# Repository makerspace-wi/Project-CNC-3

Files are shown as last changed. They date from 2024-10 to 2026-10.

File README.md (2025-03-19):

# Project-CNC-3

<br><br>
[Zur Dokumentation](https://makerspace-wi.github.io/Project-CNC-3/)<br><br>
Die CNC-3 ist ein Privatprojekt von Klaus F., dass vor einigen Jahren aus seinem Keller in den Makerspace umgezogen wurde.  
Sein Ziel war es, aus einem Bausatz eine robuste & präzise CNC-Fräse mit großer Arbeitsfläche zu bauen, die in erster Linie für Metallwerkstoffe ausgelegt ist.  
Seine Entscheidung fiel damals auf eine (China) HF-Spindel mit 24000U/min und 'Closed Loop' Steppermotor Antriebe für die 3 Achsen.  
Leider ist Klaus schon längere Zeit erkrankt, lebt momentan in einem Pflegeheim und das Projekt stand damit lange Zeit unbeachtet in unserer Metallwerkstatt.  
Gegen Ende 2024 rekrutierte das Makerspace Technikteam eine kleine Gruppe zur Fertigstellung der Fräse und es fanden sich auch Unterstützer, die das Projekt mit größeren Geldsummen mitfinanzierten. Weitere Mittel kamen aus Vereinsguthaben - wir danken an dieser Stelle auch noch mal unserem Finanzvorstand.
Diese Zusammenfassung wurde im März 2025 geschrieben, die CNC-3 ist tatsächlich kurz vor der Fertigstellung und wir sind alle sehr gespannt.
Damit ist dann auch die Zeit gekommen, wo wir kräftig dokumentieren müssen - den Einstieg findet ihr [hier](https://makerspace-wi.github.io/Project-CNC-3/)

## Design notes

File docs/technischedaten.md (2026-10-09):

## Technische Daten:
X-Achse mit 1x NEMA23 - LC57H3100 3,0Nm  4,0A & 2x mech. Endstopp (min & max)  
Y-Achse mit 1x NEMA23 - LC57H3100 3,0Nm  4,0A & 2x mech. Endstopp (min & max)  
Z-Achse mit 1x NEMA23 - LC57H380  2,0Nm  3,5A & 1x mech. Endstopp (min & max)  
    
Fräs-Spindel:Teknomotor 1,1KW ER20 230V/380V mit E-Lüfter
### Arbeitsfläche
T-Nutenplatte PT-50 von der Firma isel<br>
8mm Nuten für M6 Nutensteine  
X-Achse 700mm  
Y-Achse 1100mm  

### Fräsfläche:
X-Achse 620mm  
Y-Achse 995mm  
Z-Hub 115mm  
  
Steuerprogramm: <a href="https://www.estlcam.de/" target="_blank">Estlcam</a> von Christian Knüll (Homepage enthält auch weitere Hilfen)  
Controller: <a href="https://www.estlcam.de/tx.php/" target="_blank">Klemmenadapter XL</a> (auch von Christian Knüll)  
Minimalmengenschmierung (MMS) von <a href="https://www.end-cnc-shop.de/" target="_blank">END-CNC</a>

[Zurück zum Start](https://makerspace-wi.github.io/Project-CNC-3/)

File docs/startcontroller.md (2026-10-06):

# CNC-Controller starten

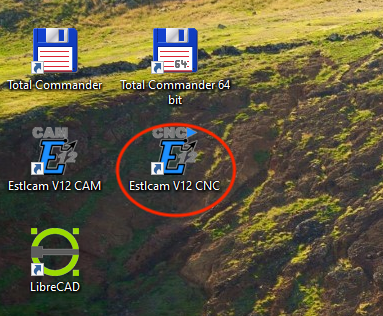
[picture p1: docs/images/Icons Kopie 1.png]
ESTLCAM Icons
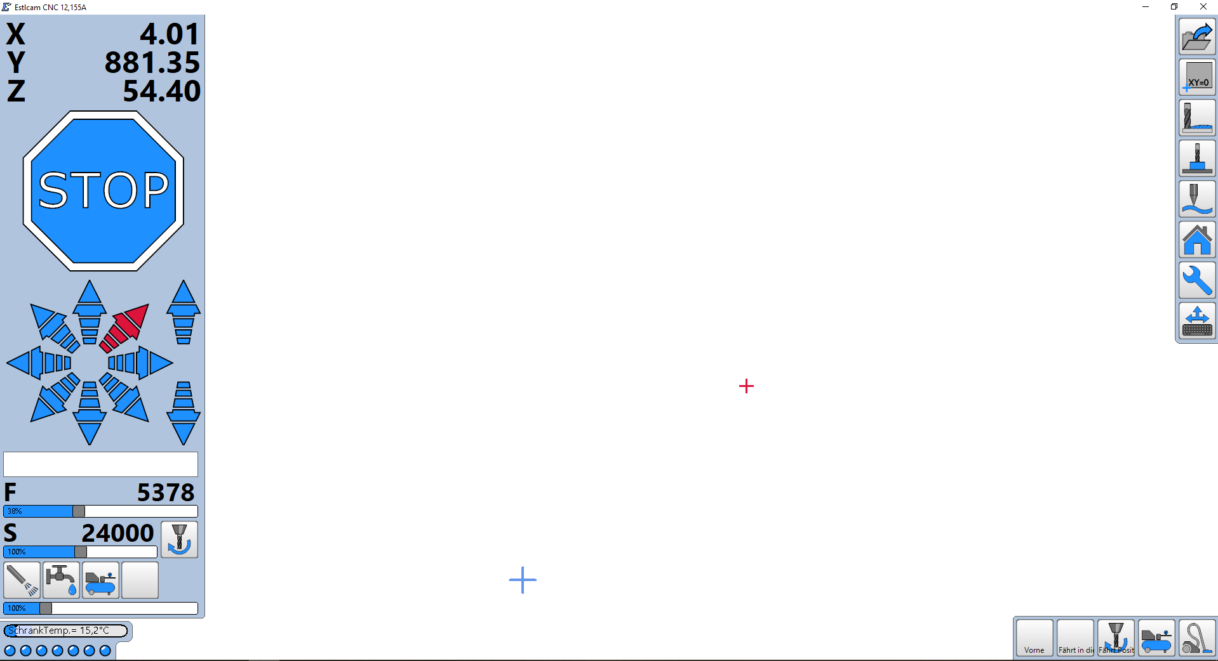
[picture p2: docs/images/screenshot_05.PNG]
CNC Controller Bildschirm
 

Der CNC-Controller wird durch Doppelklick von **Estlcam V12 CNC** auf der Oberfläche gestartet, damit werden alle Achsentreiber aktiviert, d.h. der Fräsmotor kann ab jetzt mittels Fernsteuerung, Maus oder Direkteingabe an eine Position fahren.

**Hinweis:** Jedes Feld, jede Funktion wird auf dem Bildschirm ausführlich erklärt, wenn man den Mauszeiger darüber positioniert.

## HILFE! - Ich habe eine Achse in den Endstopp gefahren 😱

Wenn dies passiert ist - bitte einfach die Ruhe bewahren! Die Software hat sofort alle Bewegungen gesperrt und am unteren Rand des Bildschirms wird auch darauf hingewiesen (in roter Schrift & blinkend). In diesem Fall die 'F11' Taste gedrückt halten und die betroffene Achse **manuell aus dem Endstopp** fahren (bei gedrückter F11-Taste darauf achten, dass in die richtige Richtung gefahren wird, also weg vom Endstopp).
  
  Wenn man trotz aller Vorsicht den Fräser auf das Werkstück gerammt hat (z.B. beim Z-Antaten), hat man einen Schleppfehler auf Z und muss unbedingt Homing/Referenzfahrt durchführen.

[Funktionen Fernsteuerung](fernsteuerung.md)

[Steuerung per Maus & Tastatur (YouTube Video)](https://www.youtube.com/watch?v=sXvNqufWKvA)

[Macros](macros.md)

[Minimalmmengenschmierung (MMS)](mms.md)

[Zurück zum Start](https://makerspace-wi.github.io/Project-CNC-3/#hilfestellungen-zum-fr%C3%A4sjob)

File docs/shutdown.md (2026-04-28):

# CNC-Fräse sicher herunterfahren

Der Shutdown-Prozess muss immer in der gleichen Reihenfolge erfolgen, damit keine Achse unerwartet fährt und die Maschine sauber für den nächsten Nutzer übergeben wird.

## Reihenfolge: Shutdown nach dem Fräsen

1. **Fräsjob beenden**  
	Warten, bis alle Achsen stehen und die Spindel komplett aus ist.
1. **MMS/Kühlung ausschalten**  
 Links unten - Falls genutzt: [MMS stoppen](mms.md)
1. **Makro [*Mitte*](macros.md) aufrufen (2. Button von links)**  
    Die Z-Achse wird in ihre maximale Höhe und Fräser weg vom Werkstück bewegt, damit Werkstück und Spannmittel gut zugänglich sind.
1. **Spannmittel lösen und Werkstück entnehmen**  
	Vorsichtig ausspannen, scharfe Kanten beachten.
1. **Maschine reinigen**  
	Späne an Tisch, Führungen und im Arbeitsraum entfernen; Werkzeugaufnahme sauber halten.
1. **Sichtprüfung auf Beschädigungen**  
	Fräser, Spannzange, Kabel und Not-Aus Bereich kurz kontrollieren.
1. **In ESTLCAM den Home Button betätigen**  
	Es wird dann die Referenzfahrt ausgeführt und die Fräse wird in die hintere, linke Ecke positioniert.	
1. **ESTLCAM sauber schliessen und PC runter fahren**  
	Dateien sichern, Projekte speichern, Programme geordnet beenden.
1. **Ausloggen am Lesegerät**  
    Die grüne Taste muss unbedingt vor dem Ausschalten des Hauptschalters gedrückt werden.   
1. **Hauptschalter ausschalten**  
	Erst ganz am Ende die Gesamtversorgung trennen.

## Sonderfall: Werkzeugwechsel während eines Jobs

* Maschine anhalten und Spindelstillstand abwarten.
* Fräser wechseln wie in der Fräser-Anleitung beschrieben.
* **Z-Nullpunkt zwingend neu setzen**, danach erst Job fortsetzen.

## Übergabe-Check

* Arbeitsfläche sauber
* Werkzeuge und Schlüssel aufgeräumt
* Keine Warnmeldung aktiv
* Maschine in sicherem Endzustand

[Reinigung](reinigung.md)

[Zurück zum Start](https://makerspace-wi.github.io/Project-CNC-3/)

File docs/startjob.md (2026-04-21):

# Fräsjob starten  

1. **Projekt/Fräsfile muss in ESTLCAM geladen sein.**  
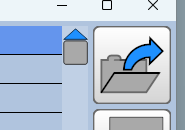
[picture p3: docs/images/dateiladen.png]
  
<br>
1. **Die angezeigte Spindeldrehzahl und der zu nutzende Fräser wird angezeigt und sollte unbedingt nochmals geprüft werden.**  
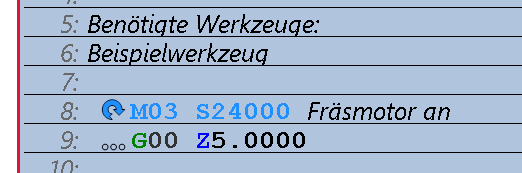
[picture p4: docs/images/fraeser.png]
  
<br>
1. **Der Fräsjob wird nach dem Betätigen des Dreiecks gestartet.**  
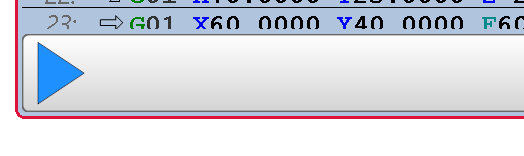
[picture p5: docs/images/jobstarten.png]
  
<br>
1. **Das Programm kann jederzeit angehalten werden und zwar durch**  
    - nochmaliges Drücken der Starttaste  
    - Bestätigen des großen STOP-Buttons (färbt sich rot mit Maus)  
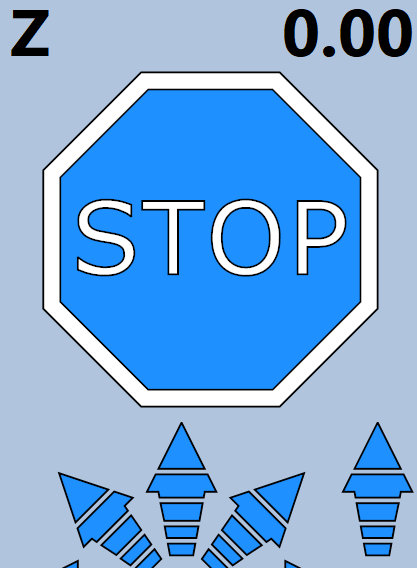
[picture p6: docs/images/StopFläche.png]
      
    - Drücken der Escape(Esc) Taste auf der Tastatur  
<br>

[Zurück zum Start](https://makerspace-wi.github.io/Project-CNC-3/)

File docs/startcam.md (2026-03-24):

# CAM-Controller starten und Projektfile anlegen

**Jeder kann sich eine Demo-Version der aktuellen [ESTLCAM Software](https://www.estlcam.de/) zu Hause auf seinem Windows-Rechner installieren, um ESTLCAM zu studieren und/oder die eigene Werkzeugliste anzulegen.** 

**Apple Nutzer können gerne das installierte ESTLCAM auf dem Rechner im Elektronikraum nutzen.**

Hinweis: Jedes Feld, jede Funktion wird auf dem Bildschirm ausführlich erklärt, wenn man den Mauszeiger darüber positioniert.  

Nach Start des CAM-Modules wird folgender Bildschirm angezeigt, immer mit der Standard Werkzeugliste.

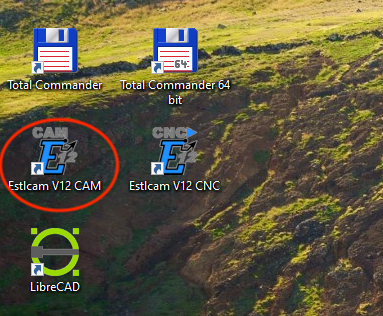
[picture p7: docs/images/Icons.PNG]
ESTLCAM Icons
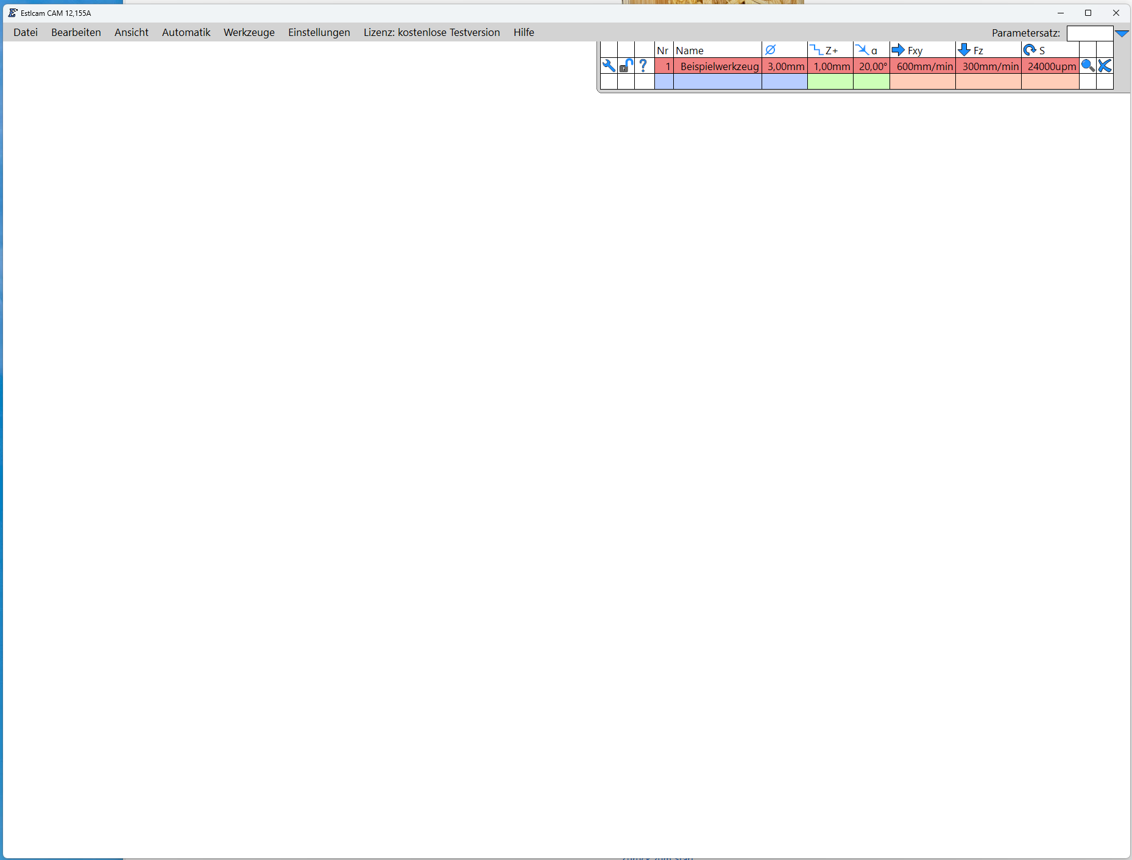
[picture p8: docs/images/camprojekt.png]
CAM Projekt Ansicht
 

## Voraussetzungen und Annahmen

- der Nutzer hat sich bereits ***intensiv*** mit allen von ESTLCAM zur Verfügung gestellten Funktionen auseinander gesetzt (wird während der Einweisung geprüft!)
- der Nutzer ist im Besitz eines dedizierten USB-Sticks
- der Nutzer hat sich ein eigenes Set an benötigten Fräsern angeschafft (Einweisung ggf. mit vorhandenen Fräsern)
- der Nutzer hat seine 2D- (DXF oder SVG) oder 3D-Zeichnung (STL) erstellt und auf dem USB-Stick gespeichert

Jeder Neuling muss zuerst alle Fräserparameter des eigenen Fräsersets in die Werkzeugliste eintragen.

[Werkzeugliste anlegen](werkzeugliste.md)

Ist dies geschehen, unbedingt die Werkzeugliste auf dem eignen USB-Stick mit eindeutigem Namen abspeichern, damit sie bei weiteren Nutzungen wieder geladen werden kann.

Also **immer** zu Beginn eines neuen Projekts **zuerst** die zu bearbeitende Zeichnung und erst dann die eigene Werkzeugliste laden, oder die Projektliste eines bereits begonnenem Projekts öffnen (dabei wird dann die korrekte Werkzeugliste angezeigt).

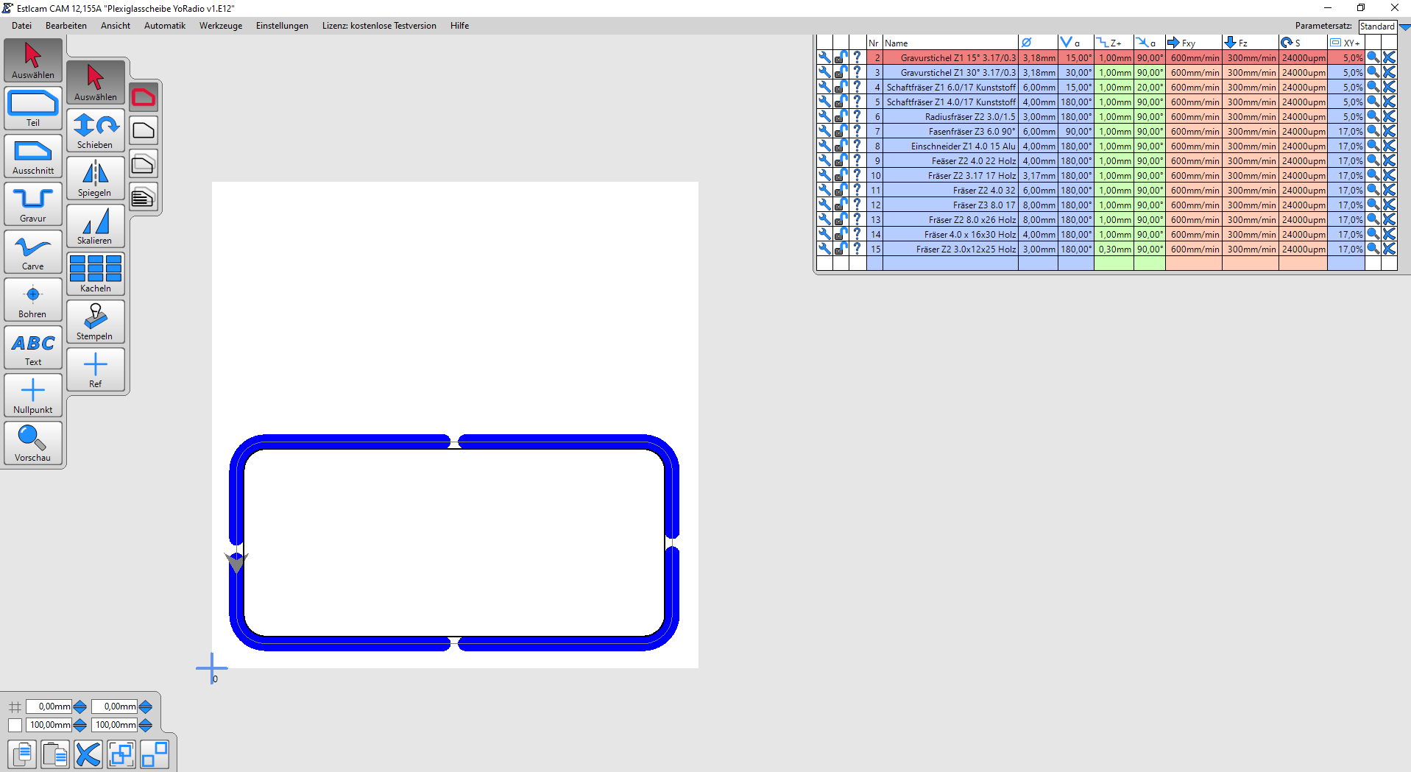
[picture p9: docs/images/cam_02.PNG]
CAM Werkzeugliste laden


An dieser Stelle wird definiert, was, wie und mit welchem Fräser gearbeitet werden soll (Aussenkanten, Ausschnitte, Taschen, Gravuren, Bohren, Texte setzen, Projektnullpunkt usw.). Dies wird bei der Einweisung an einem einfachen Projekt praktiziert und erfordert jede Menge Eigeninitiative alle ESTLCAM Funktionen zu verstehen und anzuwenden.

Am Ende dann im Menü Datei '***Projekt speichern***' wählen, dabei wird dann auch die genutzte Werkzeugliste für dieses Projekt gespeichert.

Die Projektdatei ist die wichtigste Datei, da sie alle Details enthält und auch spätere Änderungen zulässt.

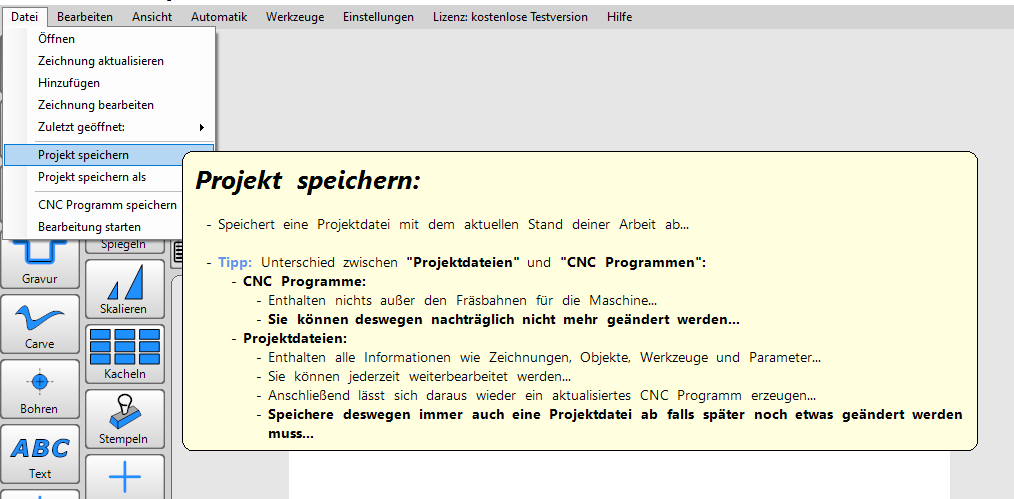
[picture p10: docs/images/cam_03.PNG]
CAM Projekt speichern


An dieser Stelle dann unbedingt die Vorschau starten und

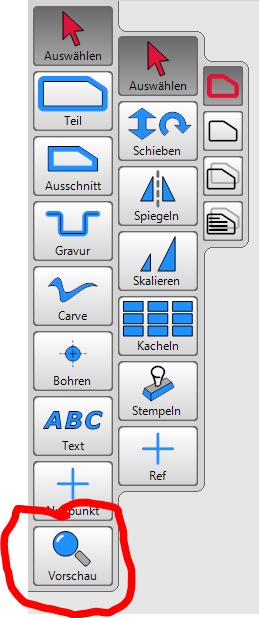
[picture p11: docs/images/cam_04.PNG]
CAM Vorschau Button


Die Anzeige für die Frässimulation ist zuerst die **Draufsicht**:

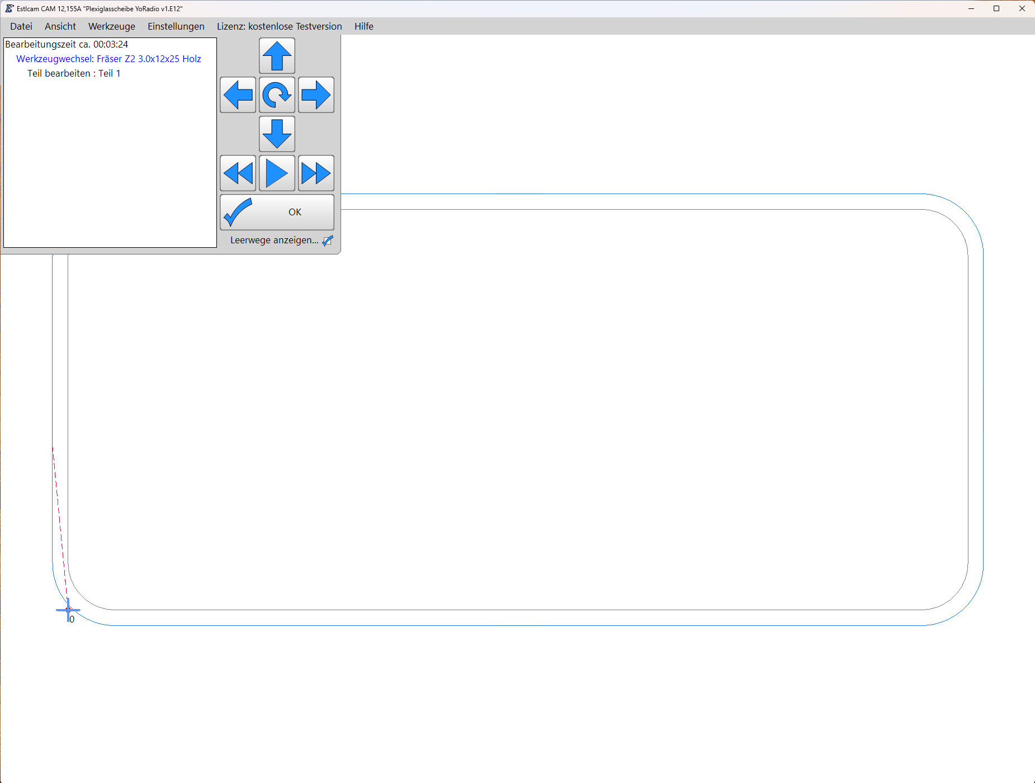
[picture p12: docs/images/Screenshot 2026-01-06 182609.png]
Frässimulation Draufsicht


ein Doppelklick auf die Bildschirmfläche führt zur zur **Raumansicht**:

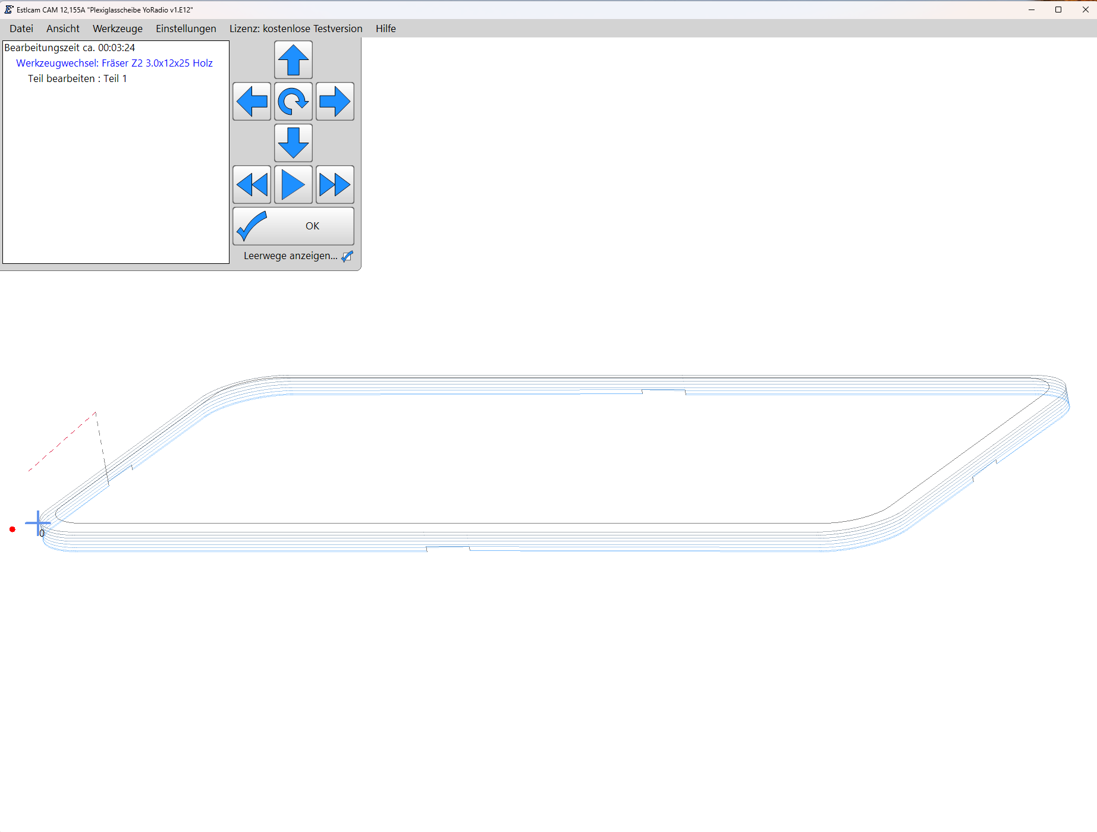
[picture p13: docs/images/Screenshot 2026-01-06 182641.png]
Frässimulation Raumsicht


ein weiterer Doppelklick bringt dich zur **Seitenansicht**:

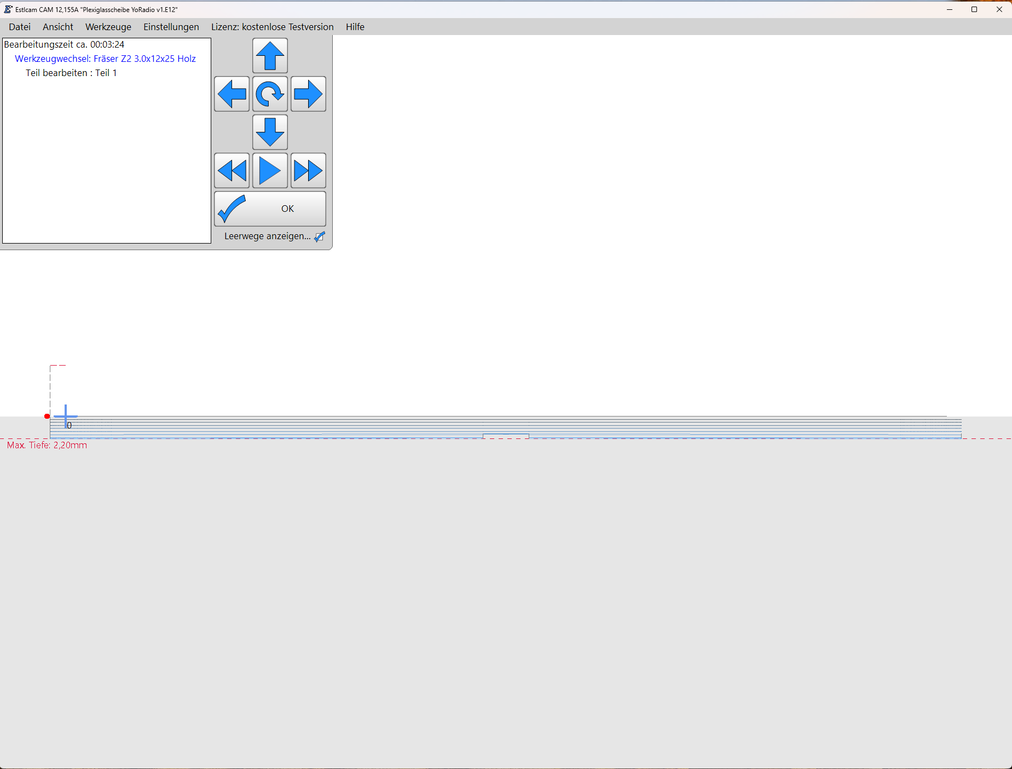
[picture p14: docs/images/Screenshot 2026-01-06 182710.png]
Frässimulation Seitenansicht


Diese Ansicht bitte genau bewerten, da sie die tatsächliche Frästiefe zeigt. <span style="color: red;">**Diese darf auf keinen Fall die Höhe von Werkstück plus Opferplatte überschreiten**</span> da die Nullung auf dem Werstück erfolgt!

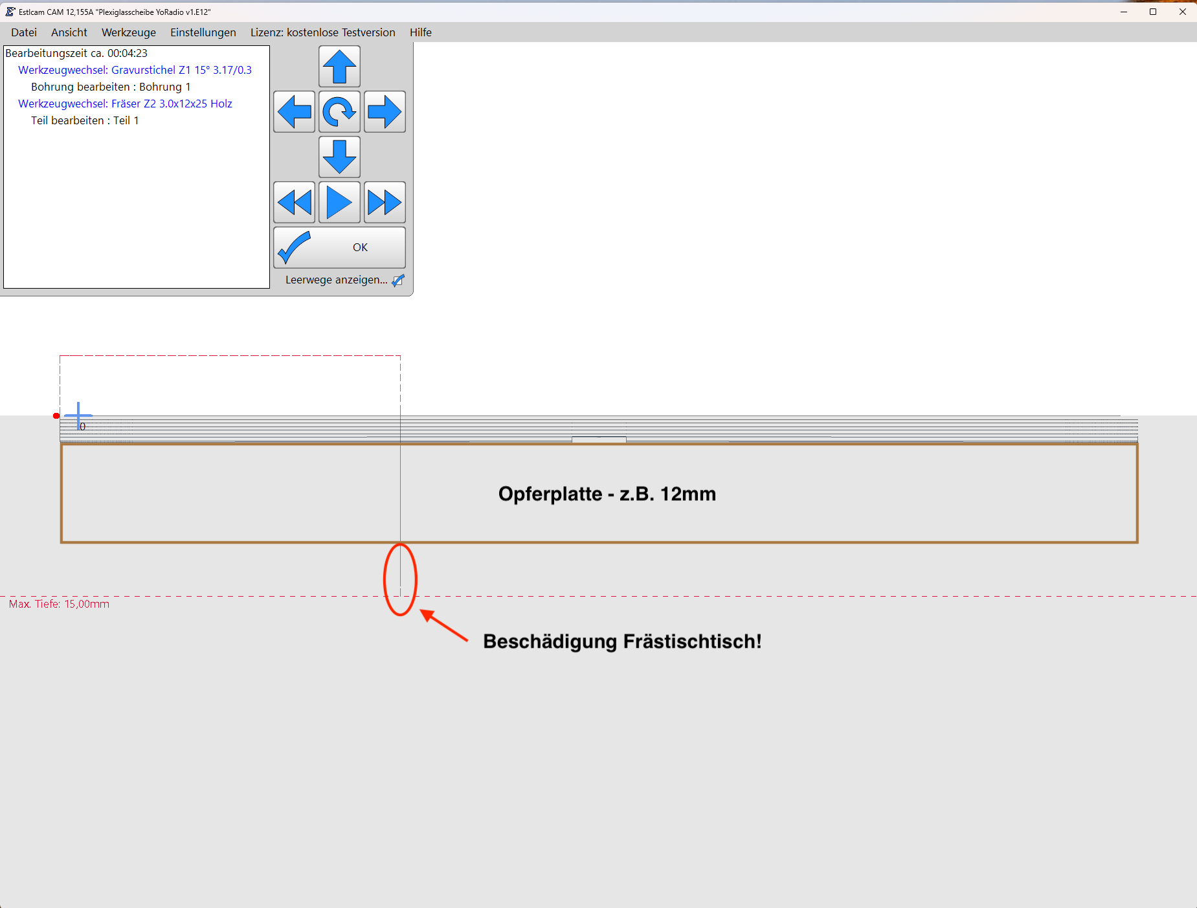
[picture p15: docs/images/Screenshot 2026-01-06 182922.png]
Frässimulation Details


Die Lage/Größe der Modellierung kann mit den Tasten oder der Maus angepasst werden. Mit der Starttaste wird die Simultion gestartet und erlaubt einen Einblick in die Fahrwege des Fräsers - der besondere Augenmerk muss dabei auf der Eintauchtiefe des Fräsers liegen. Die Simulationsgeschwindigkeit kann über die Doppeldreick-Tasten angepasst werden.

Ziel sollte es sein, das komplette Projekt mit einem Fräser abzuarbeiten, da die CNC's keinen Werkzeugwechsler haben.
Bei Projekten mit unterschiedlichen Fräsern wird zum Werkzeugwechsel die Maschine angehalten und muss nach Fräserwechsel und Z-Achsennullung wieder gestartet werden.

An dieser Stelle ist es sinnvoll, auch das **CNC Programm** zu speichern.

[Zurück](https://makerspace-wi.github.io/Project-CNC-3/#hilfestellungen-zum-fr%C3%A4sjob)  ---  [Weiter](startcontroller.md)

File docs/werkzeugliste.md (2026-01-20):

# Werkzeugliste

Die gezeigte Werkzeuglist ist lediglich ein Beispiel - die eigene Werkzeugliste sieht mit Sicherheit anders aus.

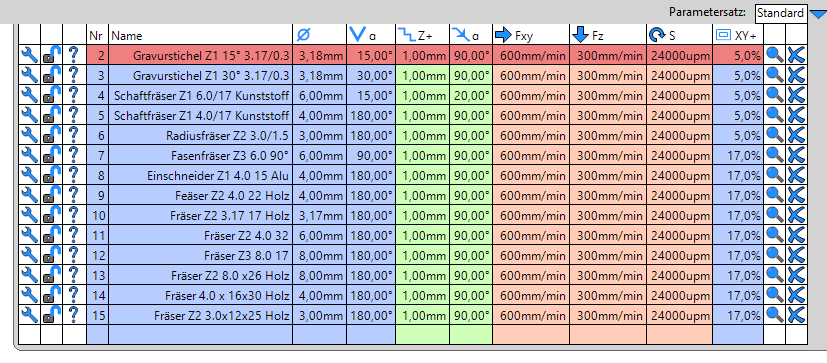
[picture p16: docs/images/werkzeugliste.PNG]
   

 Am besten gleich angewöhnen, beim Namen des Fräsers auch die wichtigsten Parameter mit anzugeben, z.B. Schaftfräser Z1 6.0/17 Kunststoff (Einzahn, Durchmesser 6mm, Frästiefe 17mm, Geeignet für Kunststoff)

Die folgenden Links unterstützen Euch beim anlegen der Werkzeugliste:  

- <a href="https://www.youtube.com/watch?v=hAuFUJFVQ4M" target="_blank">Die Listenansicht</a>
- <a href="https://www.youtube.com/watch?v=ulKHbmKEAJ8" target="_blank">Die Werkzeug Detailansicht</a>
- <a href="https://www.youtube.com/watch?v=FUI7nvCAFAw" target="_blank">Parametersätze</a>

Die Werkzeugliste kann Bilder der Fräser abspeichern und später anzeigen. Die jeweiligen Bild-Dateien können bei Sorotec oder HC-Maschinentechnik kopiert werden.  

Interessant ist es auch, sich mit dem Export als .csv Datei zu beschäftigen. Diese kann dann bequem in einem Tabellenprogramm bearbeitet werden.
 
[Zurück](startcam.md)

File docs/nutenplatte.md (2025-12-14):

# Nutenplatte

Sollte durch Fehleinstellung oder Unachtsamkeit in die Aluminium-Nutenplatte gefräst oder gebohrt werden, wird dies mit einem Betrag von € 50,-- geahndet.

Dieser Betrag wird in der Maschinenkasse hinterlegt und zu gegebener Zeit dazu verwendet, Ersatz zu beschaffen.<br>
Nach einer Beschädigung muss der Verursacher dies **zeitnah melden** und die € 50,-- zahlen.  

Wird eine Beschädigung ohne Meldung festgestellt, wird  <u>der letzte Nutzer</u> verpflichtet, den Betrag zu zahlen.
Daher ist es ratsam, unbedingt **vor** jedem Projekt zu prüfen, ob neue, nicht gemeldete Beschädigungen vorliegen.  

Beschädigungen werden im Maschinenlogbuch vermerkt.

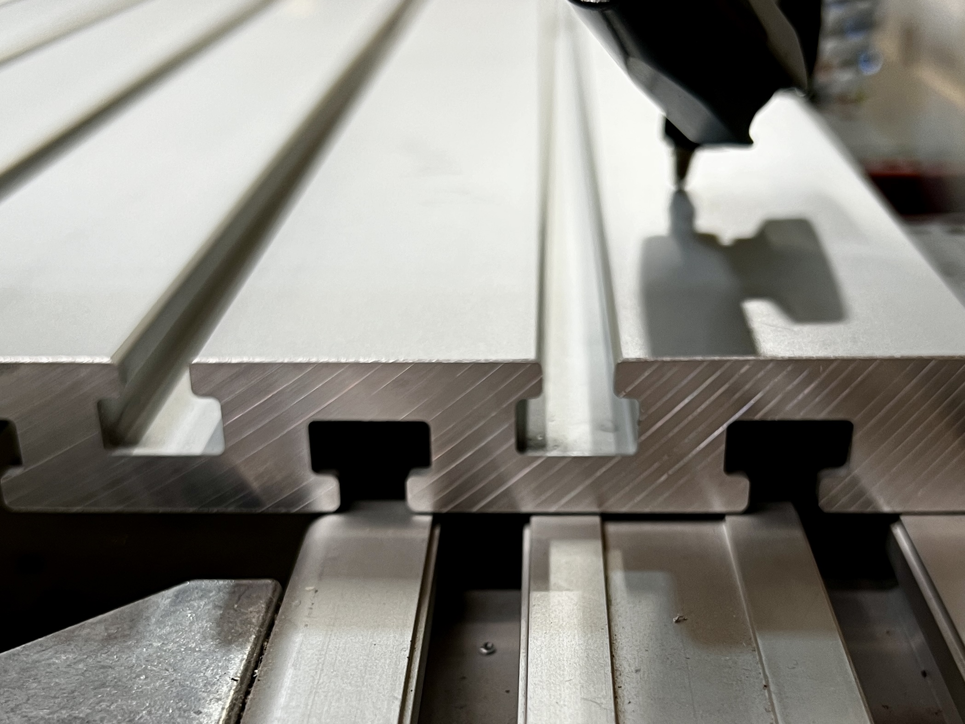
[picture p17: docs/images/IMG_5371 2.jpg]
  

[Zurück zum Start](https://makerspace-wi.github.io/Project-CNC-3/#vorbereitung)

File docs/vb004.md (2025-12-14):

# Toolslocker Zubehörbox  

Die Box im TOLO-2 beinhaltet alle notwendigen Zubehörteile wie Spannmutter, Spannzangen, Spannschlüssel, Hakenschlüssel, Konuswischer, Reinigungspinsel, T-Nutenmuttern usw. 

- <a href="https://www.upload.sorotec.de/doku/manuals/Merkblatt_Spannzangenwechsel.pdf" target="_blank">Merkblatt_Spannzangenwechsel</a>

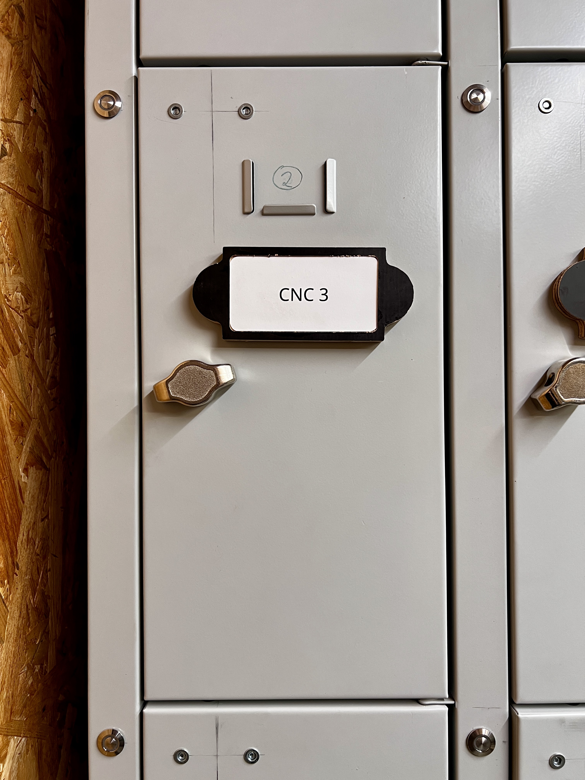
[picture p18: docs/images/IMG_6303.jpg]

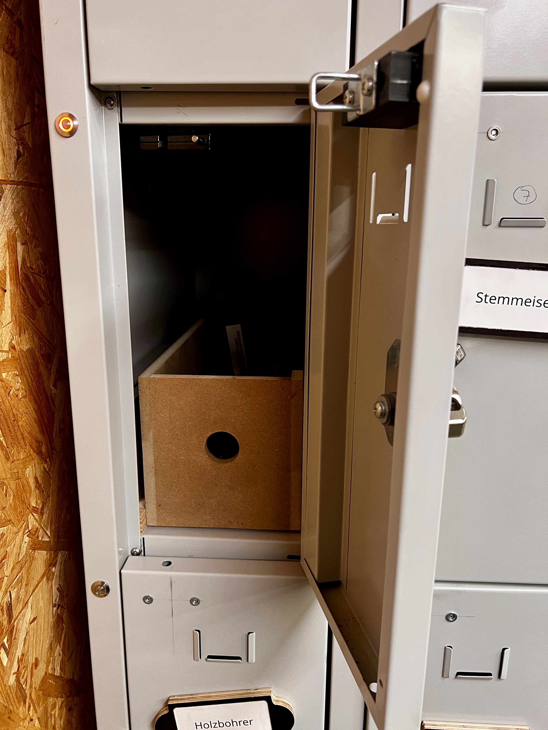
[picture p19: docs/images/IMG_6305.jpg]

  

### Spannzangenset ER 20 12teilig<br>Grössen: 2 ... 13 mm in 1 mm-Schritten plus Spannzange ER20 3,175 mm 

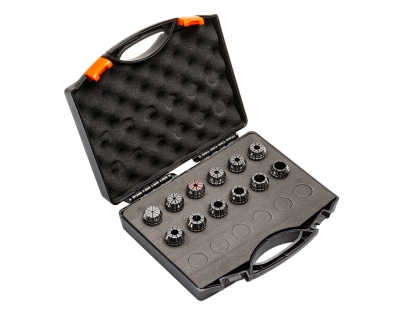
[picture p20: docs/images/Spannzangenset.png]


[Zurück zum Start](https://makerspace-wi.github.io/Project-CNC-3/#vorbereitung)

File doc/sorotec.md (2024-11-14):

# Dokumentation von SOROTEC
<strong>Handrad f&uuml;r Estlcam (EHR.ESTL.HR.01):</strong><ul>
<li><a href="https://www.upload.sorotec.de/doku/manuals/Handwheel Estlcam_data sheet_DE.pdf">Handwheel Estlcam_data sheet_DE.pdf</a>
<li><a href="https://www.upload.sorotec.de/doku/manuals/Handwheel Estlcam_data sheet_EN.pdf">Handwheel Estlcam_data sheet_EN.pdf</a></li></ul>

<strong>PUR-Motorenanschlussleitung 4 x 0,75 mm&sup2; + 2 x (2 x 0,34 mm&sup2;) (ELD.KBSG004.00.75.02.02.00.34):</strong>
<ul>
<li><a href="https://www.upload.sorotec.de/doku/manuals/SL_841_C_de.pdf">SL_841_C_de.pdf</a></li>
<li><a href="https://www.upload.sorotec.de/doku/manuals/SL_841_C_en.pdf">SL_841_C_en.pdf</a></li>
</ul>

<strong>FINDER-Koppelrelais 24 VDC 2 Wechsler 8 A (ELD.SRFIN49.52.9):</strong>
<ul>
<li><a href="https://www.upload.sorotec.de/doku/manuals/S4CDE.pdf">S4CDE.pdf</a></li>
</ul>

<strong>Schaltnetzteil 24V, 1 A, 20 W (ESN.02024):</strong>
<ul>
<li><a href="https://www.upload.sorotec.de/doku/manuals/SNTMWMDR20.pdf">SNTMWMDR20.pdf</a></li>
</ul>
<strong>Frequenzumrichter Omron M1 | 1,5 kW | 200 VAC | 1-phasig | max. 590 Hz (ZFU.1P1500.V.OM.M1):</strong>
<ul>
<li><a href="https://www.uplo=ad.sorotec.de/doku/manuals/Omron_3G3M1-AB015_Datenblatt.pdf">Omron_3G3M1-AB015_Datenblatt.pdf</a></li>
<li><a href="https://www.upload.sorotec.de/doku/manuals/I218E-EN-01+M1-STD+Datasheet.pdf">I218E-EN-01+M1-STD+Datasheet.pdf</a></li>
<li><a href="https://www.upload.sorotec.de/doku/manuals/3G3M1-STD_User_manual_I669-E1-02.pdf">3G3M1-STD_User_manual_I669-E1-02.pdf</a></li>
<li><a href="https://www.upload.sorotec.de/doku/manuals/3G3M1-KA_DE.pdf">3G3M1-KA_DE.pdf</a></li>
<li><a href="https://www.upload.sorotec.de/doku/manuals/3G3M1-AB015-230V-1,5kW-Uni.pdf">3G3M1-AB015-230V-1,5kW-Uni.pdf</a></li>
<li><a href="https://www.upload.sorotec.de/doku/manuals/Kurzanleitung_OMRON_3G3M1_DE.pdf">Kurzanleitung_OMRON_3G3M1_DE.pdf</a></li>
<li><a href="https://www.upload.sorotec.de/doku/manuals/FU-Schaltbilder-OMRON_M1_DE.pdf">FU-Schaltbilder-OMRON_M1_DE.pdf</a></li>
<li><a href="https://www.upload.sorotec.de/doku/manuals/FU-Schaltbilder-OMRON_M1_EN.pdf">FU-Schaltbilder-OMRON_M1_EN.pdf</a></li>
</ul>
<strong>Bremswiderstand 70 Ohm / 0,2 kW (ZFU.BW0070.020):</strong>
<ul><li><a href="https://www.upload.sorotec.de/doku/manuals/BremswiderstandZeichnung-0,2kW.pdf">BremswiderstandZeichnung-0,2kW.pdf</a></li>
<li><a href="https://www.upload.sorotec.de/doku/manuals/Bremswiderstand-0,2kW.step">Bremswiderstand-0,2kW.step</a></li></ul>

<strong>Netzfilter f&uuml;r FU 3G3M1 | 1,5 kW | 230 V |&nbsp;1-phasig (ZFU.NF.FIC1021SE.LL):</strong>
<ul><li><a href="https://www.upload.sorotec.de/doku/manuals/AX-FIC1021-SE-LL.pdf">AX-FIC1021-SE-LL.pdf</a></li></ul>
<strong>Frequenzumformerset 3G3M1 1,5kW 1-phasig 230V (ZFU.SET1500.1P.OM.M1):</strong>
<ul><li><a href="https://www.upload.sorotec.de/doku/manuals/Omron_3G3M1-AB015_Datenblatt.pdf">Omron_3G3M1-AB015_Datenblatt.pdf</a></li>
<li><a href="https://www.upload.sorotec.de/doku/manuals/I218E-EN-01+M1-STD+Datasheet.pdf">I218E-EN-01+M1-STD+Datasheet.pdf</a></li>
<li><a href="https://www.upload.sorotec.de/doku/manuals/3G3M1-STD_User_manual_I669-E1-02.pdf">3G3M1-STD_User_manual_I669-E1-02.pdf</a></li>
<li><a href="https://www.upload.sorotec.de/doku/manuals/3G3M1-KA_DE.pdf">3G3M1-KA_DE.pdf</a></li>
<li><a href="https://www.upload.sorotec.de/doku/manuals/Kurzanleitung_OMRON_3G3M1_DE.pdf">Kurzanleitung_OMRON_3G3M1_DE.pdf</a></li>
<li><a href="https://www.upload.sorotec.de/doku/manuals/FU-Schaltbilder-OMRON_M1_DE.pdf">FU-Schaltbilder-OMRON_M1_DE.pdf</a></li>
<li><a href="https://www.upload.sorotec.de/doku/manuals/FU-Schaltbilder-OMRON_M1_EN.pdf">FU-Schaltbilder-OMRON_M1_EN.pdf</a></li>
<li><a href="https://www.upload.sorotec.de/doku/manuals/BremswiderstandZeichnung-0,2kW.pdf">BremswiderstandZeichnung-0,2kW.pdf</a></li>
<li><a href="https://www.upload.sorotec.de/doku/manuals/Bremswiderstand-0,2kW.step">Bremswiderstand-0,2kW.step</a></li>
<li><a href="https://www.upload.sorotec.de/doku/manuals/AX-FIC1021-SE-LL.pdf">AX-FIC1021-SE-LL.pdf</a></li></ul>

<strong>Spindelset Teknomotor 1,1KW ER20 230V/380V E-L&uuml;fter (ZSP.SET.TM.DB.1100E.01):</strong>
<ul><li><a href="https://www.upload.sorotec.de/doku/manuals/Anleitung_TM_Omron.pdf">Anleitung_TM_Omron.pdf</a></li>
<li><a href="https://www.upload.sorotec.de/doku/manuals/Manual_TM_Omron_en.pdf">Manual_TM_Omron_en.pdf</a></li>
<li><a href="https://www.upload.sorotec.de/doku/manuals/TeknoMotorCatalog.pdf">TeknoMotorCatalog.pdf</a></li>
<li><a href="https://www.upload.sorotec.de/doku/manuals/COM31400404.pdf">COM31400404.pdf</a></li>
<li><a href="https://www.upload.sorotec.de/doku/manuals/COM31400404-VoltageFrequency.pdf">COM31400404-VoltageFrequency.pdf</a></li>
<li><a href="https://www.upload.sorotec.de/doku/manuals/COM31400404-PowerTorque.pdf">COM31400404-PowerTorque.pdf</a></li>
<li><a href="https://www.upload.sorotec.de/doku/manuals/TeknoMotorHandbook.pdf">TeknoMotorHandbook.pdf</a></li>
<li><a href="https://www.upload.sorotec.de/doku/manuals/3G3MX2-AB015-E-230V-1,5kW-Uni.pdf">3G3MX2-AB015-E-230V-1,5kW-Uni.pdf</a></li>
<li><a href="https://www.upload.sorotec.de/doku/manuals/FU-Schaltbilder-OMRON_DE.pdf">FU-Schaltbilder-OMRON_DE.pdf</a></li>
<li><a href="https://www.upload.sorotec.de/doku/manuals/FU-Schaltbilder-OMRON_EN.pdf">FU-Schaltbilder-OMRON_EN.pdf</a></li>
<li><a href="https://www.upload.sorotec.de/doku/manuals/SL_841_C_de.pdf">SL_841_C_de.pdf</a></li>
<li><a href="https://www.upload.sorotec.de/doku/manuals/SL_841_C_en.pdf">SL_841_C_en.pdf</a></li>
<li><a href="https://www.upload.sorotec.de/doku/manuals/S4CDE.pdf">S4CDE.pdf</a></li>
<li><a href="https://www.upload.sorotec.de/doku/manuals/SNTMWMDR20.pdf">SNTMWMDR20.pdf</a></li></ul>
<strong>Komplettsystem Teknomotor 1,1 kW | ER20 | 230 V | 24.000 Upm | E-L&uuml;fter | Frequenzumrichter (ZSP.SET.TM.DB.1100E.01.FU.M1):</strong>
<ul><li><a href="https://www.upload.sorotec.de/doku/manuals/Anleitung_TM_Omron.pdf">Anleitung_TM_Omron.pdf</a></li>
<li><a href="https://www.upload.sorotec.de/doku/manuals/Manual_TM_Omron_en.pdf">Manual_TM_Omron_en.pdf</a></li>
<li><a href="https://www.upload.sorotec.de/doku/manuals/TeknoMotorCatalog.pdf">TeknoMotorCatalog.pdf</a></li>
<li><a href="https://www.upload.sorotec.de/doku/manuals/COM31400404.pdf">COM31400404.pdf</a></li>
<li><a href="https://www.upload.sorotec.de/doku/manuals/COM31400404-VoltageFrequency.pdf">COM31400404-VoltageFrequency.pdf</a></li>
<li><a href="https://www.upload.sorotec.de/doku/manuals/COM31400404-PowerTorque.pdf">COM31400404-PowerTorque.pdf</a></li>
<li><a href="https://www.upload.sorotec.de/doku/manuals/TeknoMotorHandbook.pdf">TeknoMotorHandbook.pdf</a></li>
<li><a href="https://www.upload.sorotec.de/doku/manuals/Omron_3G3M1-AB015_Datenblatt.pdf">Omron_3G3M1-AB015_Datenblatt.pdf</a></li>
<li><a href="https://www.upload.sorotec.de/doku/manuals/3G3M1-STD_User_manual_I669-E1-02.pdf">3G3M1-STD_User_manual_I669-E1-02.pdf</a></li>
<li><a href="https://www.upload.sorotec.de/doku/manuals/I218E-EN-01+M1-STD+Datasheet.pdf">I218E-EN-01+M1-STD+Datasheet.pdf</a></li>
<li><a href="https://www.upload.sorotec.de/doku/manuals/3G3M1-KA_DE.pdf">3G3M1-KA_DE.pdf</a></li>
<li><a href="https://www.upload.sorotec.de/doku/manuals/Kurzanleitung_OMRON_3G3M1_DE.pdf">Kurzanleitung_OMRON_3G3M1_DE.pdf</a></li>
<li><a href="https://www.upload.sorotec.de/doku/manuals/3G3M1-AB015-230V-1,5kW-Uni.pdf">3G3M1-AB015-230V-1,5kW-Uni.pdf</a></li>
<li><a href="https://www.upload.sorotec.de/doku/manuals/SL_841_C_de.pdf">SL_841_C_de.pdf</a></li>
<li><a href="https://www.upload.sorotec.de/doku/manuals/SL_841_C_en.pdf">SL_841_C_en.pdf</a></li>
<li><a href="https://www.upload.sorotec.de/doku/manuals/S4CDE.pdf">S4CDE.pdf</a></li>
<li><a href="https://www.upload.sorotec.de/doku/manuals/SNTMWMDR20.pdf">SNTMWMDR20.pdf</a></li></ul>

<strong>HF-Spindel Teknomotor E-L&uuml;fter 1,1 kW | ER20 |24.000 U/min | 230 V / 400 V | COM31400404 (ZSP.TM.DB.C3140.1100.E):</strong>
<ul><li><a href="https://www.upload.sorotec.de/doku/manuals/TeknoMotorCatalog.pdf">TeknoMotorCatalog.pdf</a></li>
<li><a href="https://www.upload.sorotec.de/doku/manuals/COM31400404.pdf">COM31400404.pdf</a></li>
<li><a href="https://www.upload.sorotec.de/doku/manuals/COM31400404-VoltageFrequency.pdf">COM31400404-VoltageFrequency.pdf</a></li>
<li><a href="https://www.upload.sorotec.de/doku/manuals/COM31400404-PowerTorque.pdf">COM31400404-PowerTorque.pdf</a></li>
<li><a href="https://www.upload.sorotec.de/doku/manuals/TeknoMotorHandbook.pdf">TeknoMotorHandbook.pdf</a></li>
<li><a href="https://www.upload.sorotec.de/doku/manuals/3G3MX2-AB015-E-230V-1,5kW-Uni.pdf">3G3MX2-AB015-E-230V-1,5kW-Uni.pdf</a></li>
<li><a href="https://www.upload.sorotec.de/doku/manuals/FU-Schaltbilder-OMRON_DE.pdf">FU-Schaltbilder-OMRON_DE.pdf</a></li>
<li><a href="https://www.upload.sorotec.de/doku/manuals/FU-Schaltbilder-OMRON_EN.pdf">FU-Schaltbilder-OMRON_EN.pdf</a></li>
<li><a href="https://www.upload.sorotec.de/doku/manuals/Anleitung_TM_Omron.pdf">Anleitung_TM_Omron.pdf</a></li>
<li><a href="https://www.upload.sorotec.de/doku/manuals/Manual_TM_Omron_en.pdf">Manual_TM_Omron_en.pdf</a></li>
<li><a href="https://www.upload.sorotec.de/doku/manuals/C3140-C-DBS-P-ER20-SV-1.1kW-18000-24000RPM.stp">C3140-C-DBS-P-ER20-SV-1.1kW-18000-24000RPM.stp</a></li></ul>

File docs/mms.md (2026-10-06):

# Minimalmengenschmierung

Bildschirm unten links

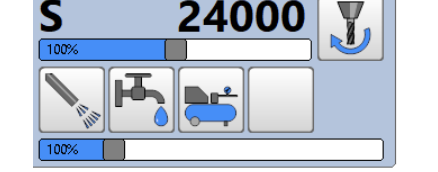
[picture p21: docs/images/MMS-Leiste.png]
  

1. (linke) Taste - Aktivieren der Minimalmengenschmierung
1. Taste - Schmiermittel (ohne Druckluft) zum entlüften
1. Taste - nur Druckluft
1. Taste - MMS-Pulsbetrieb

Wenn keine Druckluft/Schmiermittel aus dem Messingrohr kommt, Druckentlastungsventil am Schmiermittelvorratsbehälter prüfen!

[Zurück](startcontroller.md)

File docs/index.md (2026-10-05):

# Vorwort und generelles zur CNC-3 Fräse des Makerspace Wiesbaden e.V.

Die CNC-3 hat eine T-Nutenfläche von 1100mm x 700mm - davon sind 995mm x 620mm bearbeitbar.  
Weitere [Technische Daten](technischedaten.md)<br>  <br> 
Die Fräse ist zunächst nur für die Bearbeitung von Weichmetallen (Aluminium und Messing) vorgesehen.<br><br>
***Achtung wichtig!***  
* Bei der Nutzung der CNC-3 entstehen zusätzliche Kosten, bedingt durch den Verbrauch von Kühl-/Schmiermittel (ca. € 10,--/Liter) der MMS (Minimalmengenschmierung). Der Verrechnungsmodus ist noch nicht definiert - wird aber zu einem späteren Zeitpunkt hier erklärt.
* Desweiteren werden immer dann € 50,-- fällig, wenn durch eine Fehleinstellung in die (teure) T-Nutenplatte gefräst oder gebohrt wird. 
Dieser Betrag wird in der Maschinenkasse hinterlegt und zu gegebener Zeit dazu verwendet, Ersatz zu beschaffen.<br>
Nach einer Beschädigung muss der Verursacher dies **zeitnah melden** und die € 50,-- zahlen. Wird eine Beschädigung ohne Meldung festgestellt, wird  der letzte Nutzer verpflichtet, den Betrag zu zahlen.
Daher ist es ratsam, unbedingt vor jedem Projekt zu prüfen, ob neue, nicht gemeldete Beschädigungen vorliegen.  

* Jeder potentielle Nutzer der CNC-3 muß sich rechtzeitig einen <ins>eigenen</ins> Satz Alu-Fräser anschaffen - <a href="https://hc-maschinentechnik.de/Fraeser-fuer-Aluminium" target="_blank">hc-maschinentechnik</a> oder <a href="https://www.sorotec.de/shop/Zerspanungswerkzeuge/sorotec-werkzeuge/sorotec-fraesersets/" target="_blank">SOROTEC</a>
* Auf keinen Fall Änderungen an den Maschineneinstellungen vornehmen - **das ist einzig und allein Administratoren vorbehalten.**
* Unbedingt immer mit Schutzbrille und Gehörschutz arbeiten!

### Einweisungen

Die CNC3-Fräse kann nur nach Einweisung und Freischaltung benutzt werden. Die Bedienung ist sehr komplex und sollte unbedingt anhand eines konkreten Projektes erlernt werden.  
[Ablauf Einweisung](einweisung.md)

### Details zur Bedienung, Einrichtung & Wartung können in der folgenden Dokumentation nachgelesen werden.  

!!! Bei Unsicherheiten in der Bedienung **IMMER** einen Einweiser kontaktieren !!!  

[Bezugsquellen und Hilfsmittel](bezugsquellen.md)
<br><br>

- Hilfreiche Kurzerklärungen von Christian Knüll, dem Erfinder von Estlcam 
  - <a href="https://estlcam.de/index.php#Help" target="_blank">ESTLCam Hilfeseite</a>
  - <a href="https://www.youtube.com/watch?v=od0ZFGGbvX8" target="_blank">ESTLCam Craskurs</a>
  - <a href="https://www.youtube.com/watch?v=3ujPAEB8xeg" target="_blank">Die Hilfefunktionen</a>
  - <a href="https://www.youtube.com/watch?v=sXvNqufWKvA" target="_blank">Tastenbelegung NUMPAD + Maus</a>
  - <a href="https://www.youtube.com/@ChristianKnuell/videos" target="_blank">weitere auf der YOUTUBE Seite von Christian Knüll</a>
<br>
- Hilfreiche Links zur Verwendung von AutoCAD Fusion360  
  - <a href="https://www.youtube.com/@cadcamstuff" target="_blank">Fusion360 Tutorials with Lars Christensen</a>
  - <a href="https://www.youtube.com/@fusionfurholzbastler1901/featured" target="_blank">Fusion360 für Holzbastler</a>
  - <a href="https://www.youtube.com/@fusionfurholzbastler1901/playlists" target="_blank">Fusion360 für Holzbastler - Playlist</a>
  - <a href="https://www.youtube.com/@knowhowschmiede/featured" target="_blank">know-how-schmiede</a>
  - <a href="https://www.youtube.com/@HaraldHartmann/videos" target="_blank">Harald Hartmann</a>
  - viele weitere Tutorials unter Google Suche <a href="https://www.youtube.com/@HaraldHartmann/videos](https://www.google.com/search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" target="_blank">Fusion360 Tutorials</a>

## Fräsprojekt Ablauf

### Vorbereitung

* [Zubehör (Schlüssel für Spannzange und Passende Spannzange) aus ToolsLocker-2 - Fach: CNC-3 entnehmen](vb004.md)
* [T-Nutenplatte auf ungemeldete Beschädigungen prüfen und ggf. sofort melden](nutenplatte.md)
* [Werkstück (Aluminium) und Opfermaterial (Multiplex Holz) auf Grobmaß sägen und bereit halten](opfermaterial.md)
* [Füllstand des Schmiermittels prüfen - Einweiser oder Admin informieren wenn niedrig](vb002.md)
* Schutzbrille & Gehörschutz bereit legen und später beim fräsen unbedingt tragen
* [CNC-3 einschalten und mit RFID-Chip anmelden](vb001.md)

## Hilfestellungen zum Fräsjob

* [Startsituation - CAM Projektfile generieren](startcam.md)
* [CNC Controller starten](startcontroller.md)
* [Fräser montieren](fraeser.md)  
* [Werkstück auf Arbeitsfläche einspannen](werkstueck.md)
* [Nullpunkte definieren](nullpunkt.md)
* [Fräsjob starten](startjob.md)

## Nachbereitung  

* [Fräse runter fahren (ausschalten)](shutdown.md)

* [Endreinigung - Zeitaufwand ca. 1 Stunde](reinigung.md)

## Weiterführende Dokumentationen

[Fräserauswahl](https://github.com/makerspace-wi/Projekt-CNC2-Holzfraese/tree/main/images/fraeser_verwendung_schaftfraeser.png)<br>

<a href="https://cdn.jsdelivr.net/gh/makerspace-wi/Project-CNC-3@main/docs/schnittwerte.pdf" target="_blank" rel="noopener">Schnittwerteberechnungen</a>

<a href="https://cdn.jsdelivr.net/gh/makerspace-wi/Project-CNC-3@main/docs/Clamping_Set_58_de.pdf" target="_blank" rel="noopener">Spann Pratzen Set Teileliste</a>

----
[Forum - Doku CNC Frieda](https://www.rc-network.de/threads/fr%C3%A4se-frieda.560454/)

[Start Aufbau Frieda](https://www.rc-network.de/threads/fr%C3%A4se-frieda.560454/page-7#post-6101748)

[Alternative: Aufbauvideos Fenja](https://youtube.com/playlist?list=PLLCksGowj_HlLhqURt2nQoHIq9-4l2GwC)

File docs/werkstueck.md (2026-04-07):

# Werkstück einspannen

Die richtige Reihenfolge beim Einspannen verhindert verrutschende Teile, Kollisionen und Ausschuss.

## Reihenfolge: Werkstück einspannen

1. **Maschine sichern**  
	Spindel steht, kein laufender Job, Arbeitsbereich frei von Werkzeugen und Spänen.
2. **Auflagefläche reinigen**  
	Nutenplatte/Opfermaterial und Unterseite des Werkstücks sauber und plan machen.
3. **Passendes Spannkonzept wählen**  
	Je nach Teil: Schraubstock, Niederzugspanner, Spannpratzen oder Direktverschraubung.
4. **Werkstück grob positionieren**  
	So platzieren, dass alle Bearbeitungsflächen erreichbar sind und keine Kollision mit Spannmitteln entsteht.
5. **Anschläge/Referenzkante setzen**  
	Werkstück an fester Kante oder Anschlag ausrichten, damit die Nullpunktfindung reproduzierbar ist.
6. **Vorfixieren, noch nicht voll anziehen**  
	Spannmittel nur leicht anziehen, damit sich die Position noch fein korrigieren lässt.
7. **Ausrichten und Planlage prüfen**  
	Mit Lineal/Winkel/Sichtkontrolle auf Verkanten achten, bei Bedarf neu setzen.
8. **Endgültig festspannen (kreuzweise)**  
	Mehrere Spannpunkte gleichmässig in kleinen Schritten anziehen, um Verzug zu vermeiden.
9. **Haltekraft prüfen**  
	Werkstück von Hand kräftig bewegen: kein Kippeln, kein Verschieben.
10. **Freigang und Kollisionsfreiheit prüfen**  
	Geplanten Fräsweg gedanklich abfahren: Fräser, Spannmittel, Schraubenhöhen und Kabel beachten.
11. **Nullpunkt setzen**  
	Erst nach finalem Einspannen X/Y/Z-Nullpunkt bestimmen und dokumentieren.
12. **Trockenlauf/Start-Check**  
	Wenn möglich ohne Materialeingriff prüfen, dann erst Fräsjob starten.

## Wichtige Hinweise

* Nie auf Späne spannen, auch kleine Partikel verfälschen die Lage.
* Spannmittel dürfen den Fräsbereich nicht verdecken.
* Dünne oder lange Werkstücke zusätzlich gegen Schwingung abstützen.
* Nach den ersten Zustellungen Spannkraft kurz nachprüfen.

[Zurück zum Start](https://makerspace-wi.github.io/Project-CNC-3/)

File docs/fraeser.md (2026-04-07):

# Fräser montieren

Die korrekte Montage ist entscheidend für Rundlauf, Werkzeugstandzeit und Sicherheit.
Unsachgemässe Montage führt schnell zu schlechtem Schnittbild, Werkzeugbruch oder Beschädigung von Werkstück und Maschine.

## Benoetigtes Material

* Passende Spannzange zur Schaftgroesse des Fräsers (z. B. 6 mm, 8 mm)
* Zwei passende Schlüssel für Spannmutter/Spindel
* Sauberes Tuch (fusselfrei)
* Optional: etwas Isopropanol zum Entfetten

## Sicherheitsregeln vor dem Montieren

* Maschine in sicheren Zustand bringen (keine laufende Spindel, kein aktiver Vorschub)
* Frühzeitig sicherstellen: Estlcam-Job noch **nicht** gestartet
* Später beim Fräsen immer Schutzbrille und Gehoerschutz tragen
* Lange Haare sichern, keine losen Kleidungsstücke

## Schritt-für-Schritt: Fräser korrekt montieren

1. **Maschine stoppen und absichern**  
	Notfalls auf sicheren Zustand gehen: Spindel aus, keine Bewegung der Achsen.
2. **Alten Fräser entfernen (falls vorhanden)**  
	Mit den beiden Schlüsseln gegenhalten und Spannmutter loesen. Fräser gerade nach unten herausnehmen.
3. **Spannzange und Spannmutter prüfen**  
	Nur die Spannzange verwenden, die exakt zum Schaftdurchmesser passt.
4. **Kontaktflächen reinigen**  
	Innenkonus, Spannzange und Fräserschaft sauber und trocken abwischen. Keine Späne, kein Oel, kein Schmutz.
5. **Fräser einsetzen**  
	Fräser in die Spannzange einschieben, aber vorher prüfen, dass die Fräserschnittlänge (SL) für den Fräsvorgang ausreichend ist.  
	Schaft ausreichend tief spannen (Faustregel: mindestens 2/3 der Spannzangenlänge, besser tiefer).  
	<span style="color: red;">Schneiden dürfen nicht in der Spannzange sitzen!</span>
7. **Spannmutter festziehen**  
	Mit beiden Schlüsseln gleichmässig und kräftig anziehen. Nicht mit Verlängerung überdrehen.
8. **Sitz und Rundlauf prüfen**  
	Sichtkontrolle: Werkzeug sitzt gerade, keine Schiefstellung, lässt sich von Hand nicht herausziehen.

## Haüfige Fehler vermeiden

* Falsche Spannzange für den Fräserdurchmesser
* Verschmutzte Spannzange oder verschmutzter Schaft
* Zu geringe Einspanntiefe
* Fräser bis ganz nach unten auf Anschlag gesteckt
* Zu schwach oder ungleichmässig angezogen

## Kurzer Check vor dem Start

* Fräsertyp stimmt mit CAM-Job überein
* Werkzeuglänge und Nullpunkt nach Montage neu geprüft
* Werkstück fest eingespannt
* MMS/Kühlschmierung eingestellt (falls benoetigt)

**Wenn Unsicherheiten bestehen, vor dem Start immer einen Einweiser kontaktieren.**

[Zurück zum Start](https://makerspace-wi.github.io/Project-CNC-3/)

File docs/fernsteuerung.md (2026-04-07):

# Funktionen Handrad Fernsteuerung

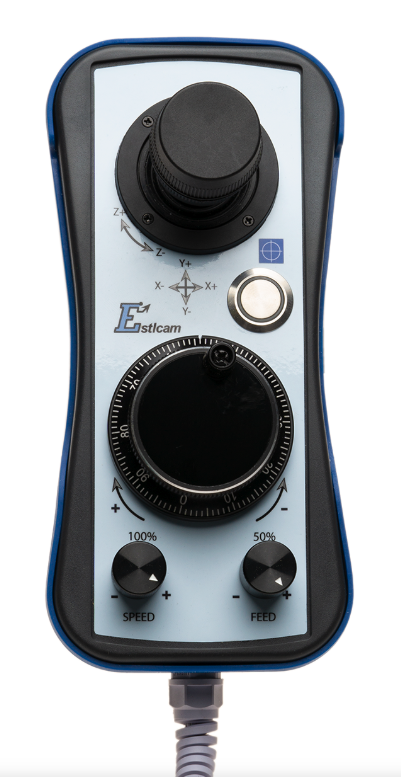
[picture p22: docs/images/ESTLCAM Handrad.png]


Der Joystick der Fernsteuerung hat folgende Funktionen:

- hoch/runter: Bewegung der Y-Achse nach hinten/vorne - je größer die Auslenkung, desto schneller die Achsenbewegung.
- links/rechts: Bewegung der X-Achse nach links/rechts - je größer die Auslenkung, desto schneller die Achsenbewegung.
- Drehung des Joysticks nach rechts/links: Bewegung der Z-Achse nach open/unten - je weiter die Drehung, desto schneller die Achsenbewegung.

Der Drehgeber bewegt immer die Achse, die zuletzt mit dem Joystick verfahren wurde - also automatisch die richtige. 

Leuchtender Taster (blau) in der Mitte: Abnullen -> kurz drücken nullt die ausgewählte Achse, lang drücken nullt alle ab.

## Programmablauf steuern

- Ein Druck auf den mit "SPEED" beschrifteten Knopf **startet oder stoppt die Spindel** manuell
- Ein Druck auf den mit "FEED" beschrifteten Knopf **startet das geladene CNC Programm**
- Durch drehen am "FEED" Knopf kann die Vorschubgeschwindigkeit von 0 bis 100% angepasst werden
- Durch drehen am "SPEED" Knopf kann die Spindeldrehzahl von 0 bis 200% variiert werden
- Drücken bei laufendem Programm einen der beiden Knöpfe **pausiert das Programm**

[Zurück](startcontroller.md)

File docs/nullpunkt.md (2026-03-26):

# Nullpunkte festlegen

Die Achsennullpunkte bestimmen, wo der CNC-Job startet.  
Falsch gesetzte Nullpunkte führen schnell zu Massfehlern, Luftfräen oder Kollisionen.  
Im folgenden wird zunächst die manülle Vorgehensweise erklärt.

## Ziel

* X0 / Y0: Bezugspunkt auf dem Werkstück gemäss CAM-Setup
* Z0: Höhenbezug auf Werkstückoberfläche (wie bei der CNC-3 im Setup definiert)

## Vorbedingungen

* Fräser ist korrekt montiert und festgezogen
* Werkstück ist final gespannt (danach nicht mehr verschieben)
* CAM-Datei ist geladen und der gewünschte Nullpunkt ist bekannt
* Spindel steht still

## Schritt-für-Schritt: Achsennullpunkte einstellen

1. **Nahe an den Zielpunkt fahren**  
	Mit Fernsteuerung, Tastatur oder Maus die Achsen in langsamer Geschwindigkeit in die Nähe des geplanten Nullpunkts bewegen.
2. **X und Y exakt ausrichten**  
	Fräsermittelpunkt auf die gewünschte Ecke oder Markierung positionieren.  
	Zum Schluss nur noch mit kleinen Schritten (Feinverstellung) korrigieren.
3. **X/Y nullen**  
	Im CNC-Controller die aktuelle Position als X0 und Y0 setzen.  
 	z.B. leuchtender Taster (blau) in der Mitte: Abnullen -> kurz drücken nullt die ausgewählte Achse (lang drücken nullt alle ab!) oder
4. **Z-Höhe anfahren**  
	Fräser vorsichtig in Z nach unten fahren, bis der Bezugspunkt fast erreicht ist.
5. **Z exakt setzen**  
	Je nach Vorgehen in der Einweisung:
	* Direkt auf Oberfläche tasten (sehr kleine Schritte), oder
	* Papiermethode verwenden (Papier klemmt leicht zwischen Werkzeug und Fläche)
6. **Z nullen**  
	Aktuelle Z-Position als Z0 setzen.
7. **Sicherheitsabstand anfahren**  
	Werkzeug einige Millimeter in Z nach oben fahren.

## Wichtige Hinweise

* Nullpunkte immer **nach** dem finalen Spannen setzen
* Nach Fräserwechsel Z-Nullpunkt zwingend neu setzen
* Wenn X/Y-Bezug verschoben wurde: X und Y neu setzen
* Bei Unsicherheit lieber erneut antasten statt mit falschem Nullpunkt starten

## Typische Fehler

* CAM-Nullpunkt (z. B. linke vordere Ecke) passt nicht zum real gesetzten Nullpunkt
* Z-Nullpunkt auf falscher Fläche gesetzt (Werkstück statt Opfermaterial oder umgekehrt)
* Nach dem Nullen wurde das Werkstück nochmals verschoben
* Z zu schnell angefahren und Werkzeug/Fläche berührt

## 20-Sekunden-Check vor Start

* X0/Y0/Z0 sind gesetzt und plausibel
* Werkzeug ist auf sicheren Z-Abstand gefahren
* Simulation/Vorschau passt zur realen Position
* Erst jetzt Fräsjob starten

[Zurück zum Start](https://makerspace-wi.github.io/Project-CNC-3/)

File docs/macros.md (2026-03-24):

# Erklärung der angelegten Macros

Die Macros sind auf dem Bildschirm unten/rechts angeordnet.

  

1. **VORNE** - fährt die Z-Achse hoch, den Fräser in die Parkposition vorne/inks und <span style="color: red;"> setzt X- , Y- und Z-Achsen auf '0'</span>
1. **MITTE** - fährt die Z-Achse hoch und den Fräsmotor in die Mitte der Arbeitsfläche
1. **Fahre in Wechselposition** - (wie in 1.) **ohne die Achsen zu nullen**
1. **Kompressor einschalten** - aktiviert die Drucklufterzeugung
1. **Staubsauger einschalten**

[Zurück](startcontroller.md)

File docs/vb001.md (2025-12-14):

# CNC-3 einschalten und mit RFID-Chip anmelden
- zuerst sicherstellen, dass die CNC-3 an das Stromnetz angeschlossen ist  

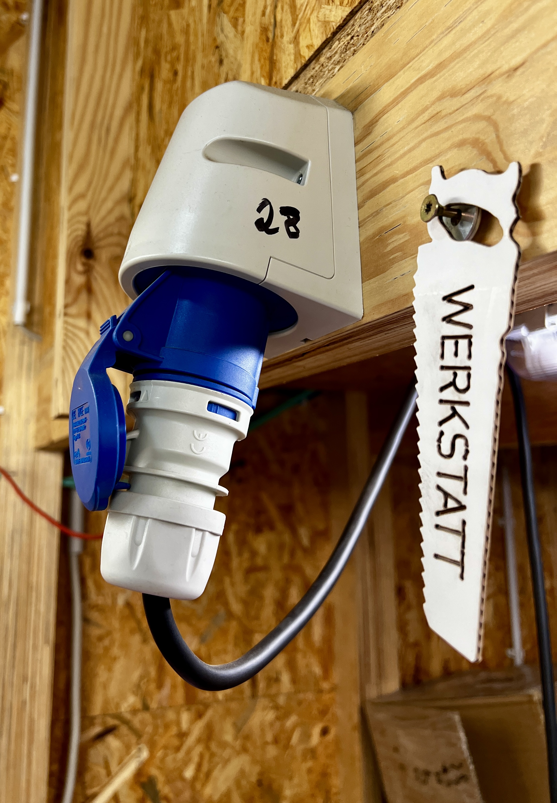
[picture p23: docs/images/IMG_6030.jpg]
  

- den Hauptschalter auf "ON" schalten und prüfen, dass der NOT-AUS und der "NOT-STOP" nicht gedrückt sind  

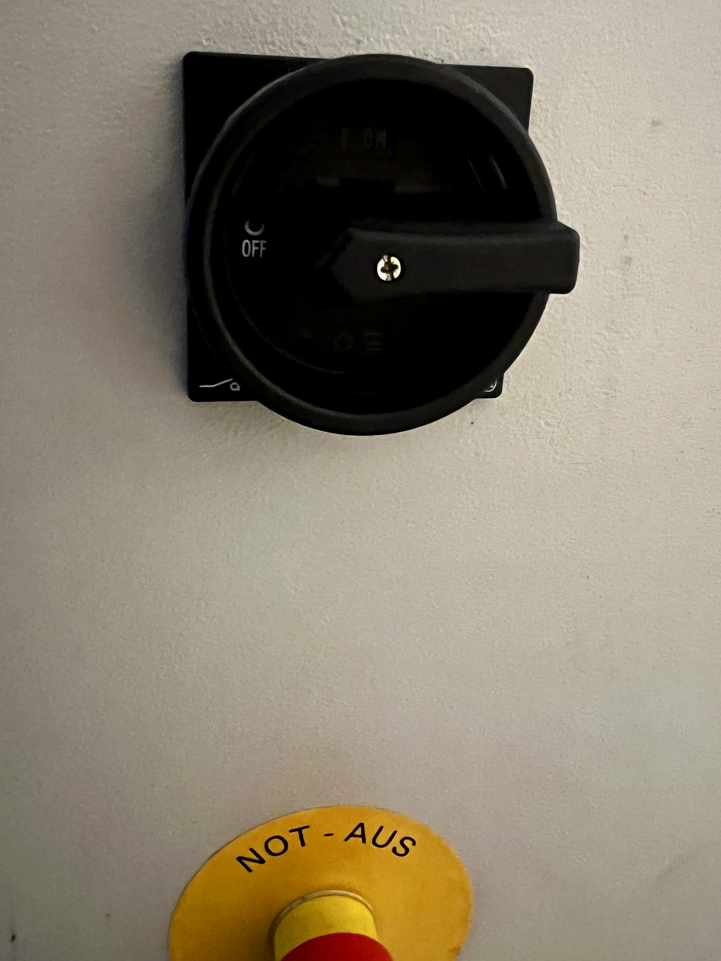
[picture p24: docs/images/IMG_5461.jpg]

  

- Nach dem 'booten' zeigt sich der Desktop mit Startbildschirm  



- mit RFID-Chip die CNC-3 aktivieren - setzt voraus, dass das Mitglied freigeschaltet ist.  
Gelegentlich kann es sein, dass das Lesegerät den Chip nicht erkennt, dann - und nur dann - den kleinen roten RESET-Button drücken und abwarten, bis sich die CNC-3 mit unserem Zugangssystem synchronisiert hat. Danach sollte der Chip ohne Probleme erkannt werden.  

  

**Falls versäumt wurde sich einzuloggen, erscheint folgender Bildschirm nach starten des CNC-Programms:**    



***Bitte unbedingt beachten !***  

**Die Frässpindel muss immer vor den Fräsarbeiten ohne Last ca. 3 Minuten bei 6000 U/min warm laufen!**  

[Zurück zum Start](https://makerspace-wi.github.io/Project-CNC-3/#vorbereitung)

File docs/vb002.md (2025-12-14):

# Schmiermittelstand prüfen



Falls der Schmiermittelstand im Vorratsbehälter unter der aufgeklebten Markierung ist, ***auf keinen Fall*** selbst nachfüllen, sondern das Technikteam informieren (Michael M. -  Holger G. - Dieter H. - Elian T. - Orlando E.)

[Zurück zum Start](https://makerspace-wi.github.io/Project-CNC-3/#vorbereitung)

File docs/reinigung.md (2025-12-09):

# Reinigungsprozess

Nach der Fräsarbeit komplette Fräse (auch unter den Kabelführungen) und den gesamten Bodenbereich rund um und unter der Fräse reinigen - dafür ca. 1 Stunde einplanen.  

[Zurück zum Start](https://makerspace-wi.github.io/Project-CNC-3/)

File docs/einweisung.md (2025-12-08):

# Ablauf Einweisung

1. Einweisung erfolgt NUR mit konkretem Projekt (Allgemeine Einweisungen sind erfahrungsgemäß nicht sinnvoll)
- Der Einweiser stellt zu Beginn sicher, dass aureichende Kenntnise zur Anwendung von ESTLCAM vorhanden sind
- Freischaltung frühestens nach dem 2. eigenständigem Projekt, bzw. nach Einschätzung des Einweisers !  
1. Abfrage Projektdetails & Entscheidung, ob das Projekt sinnvoll an der CNC umsetzbar ist
- mit anderen Maschinen / Werkzeugen einfacher umsetzbar ?
- max. Abmessungen
- Geometriebesonderheiten (Rundungen, Hinterschnitte, ...)
- Zeitfaktor
- Material, hier nur Weichmetalle wie Aluminium, Messing ...  
1. Abfrage der Erfahrung bzgl. CAM Programmierung und CNC gesteuerten Maschinen
- KEINE Grundlagen CAM Programmierung vorhanden
  - Auf verschiedene CAM Tutorials verweisen (dazu gibt es mittlerweile ausreichend Material im Internet - siehe Wiki)
  - Um Eigeninitiative bitten, um sich in die Grundlagen einzuarbeiten
- Grundlagen CAM Programmierung vorhanden
  - Im optimalen Fall wurde bereits was im CAM Programm der Wahl vorbereitet
  - Gemeinsam die Projektdetails anhand des CAM Programms besprechen
1. CAM Projekt gemeinsam kontrollieren, überarbeiten und simulieren
- Bearbeitungsnullpunkt
- Bearbeitungsreihenfolge - Bearbeitung von innen nach außen (Konturen i.d.R. zuletzt)
- Werkzeugwahl
  - Fräserauswahl (siehe Sorotecdokumente)
  - Drehzahlen und Vorschubberechnung (hier eher konservativ vorgehen)
- Simulieren und prüfen auf mögliche Kollisionsgefahren
- Korrekten Postprozessor einrichten und GCode erzeugen/überprüfen/ simulieren
1. Persönliche Schutzausrüstung (Brille, Ohrenschutz, ...)
1. Maschineneckdaten und -funktion erklären (teilweise schon beim CAM Programmieren)
- max. Abmessungen (Platz für Spannmöglichkeiten beachten)
- Maschinennullpunkt erklären
- Einschaltprozess
  - PC
  - Steuerung
- Erklären der Achsen und Verfahrrichtungen samt Handrad
- Schmiermittel checken (Schmiermittelstand, ...)
- Warmlaufphase
- Einrichtung Rohteil
  - Opferplatten (Siebdruck- oder Multiplesplatten)
  - Aufspannung Rohteil
  - Spannmittelarten und -position (penibel mögliche Kollision vermeiden)
- Werkzeug-/ Fräserwechsel
- Einrichtung Bearbeitungsnullpunkt auf/an Rohteil
- Programm einlesen
- Absaugung
- Bearbeitungsstart & Abbruch erklären (Notaus, ...)
- Programm- und/oder Werkzeugwechsel (falls nötig)
1. Nachbereitung
- Abspannen
- Aufräumen
- Ausschalten

1. Freischaltung erfolgt nach Einschätzung des Einweisers - bis zu diesem Zeitpunkt darf die Maschine nur in Anwesenheit einer Person vom Technik Team genutzt werden (4 Augen Prinzip)

[Zurück zum Start](https://makerspace-wi.github.io/Project-CNC-3/)

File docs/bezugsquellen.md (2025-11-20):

# Bezugsquellen und andere interessante Links

## Fräser

- <a href="https://www.sorotec.de/shop/Zerspanungswerkzeuge/sorotec-werkzeuge/" target="_blank" rel="noopener noreferrer">SOROTEC CNC-Werkzeuge</a>
- <a href="https://hc-maschinentechnik.de/Fraeser-Bohrer" target="_blank" rel="noopener noreferrer">HC-Maschinentechnik</a>

## Materialien

- <a href="https://hc-maschinentechnik.de/Rohmaterialien" target="_blank" rel="noopener noreferrer">HC-Maschinentechnik</a>
- <a href="https://gammaflow.de/blogs/cnc-blog/cnc-schnittdaten-verstehen-teil-1-einleitung" target="_blank" rel="noopener noreferrer">CNC-Schnittdaten verstehen</a>

## Hilfsrechner

- <a href="https://gammaflow.de/pages/schnittdatenrechner" target="_blank" rel="noopener noreferrer">Gammaflow Online Schnittdatenrechner</a>
- <a href="https://app.sorotec.de/" target="_blank" rel="noopener noreferrer">SOROTEC App</a>
- <a href="https://schnittdaten.meusburger.com/" target="_blank" rel="noopener noreferrer">Meusburger Schnittdaten-Kalkulator</a>

[Zurück zum Start](https://makerspace-wi.github.io/Project-CNC-3/)


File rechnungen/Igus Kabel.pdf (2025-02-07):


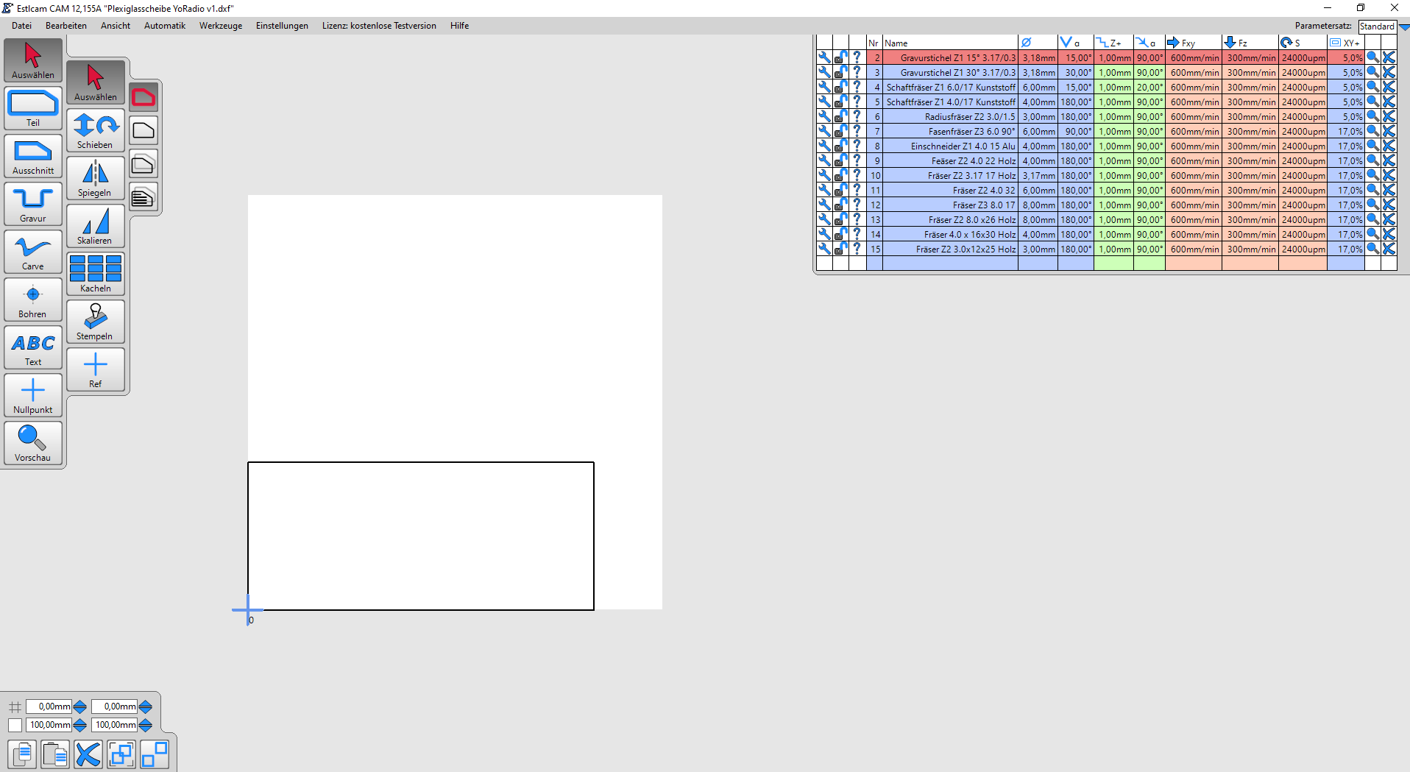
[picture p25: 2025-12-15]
docs/images/cam_01.PNG

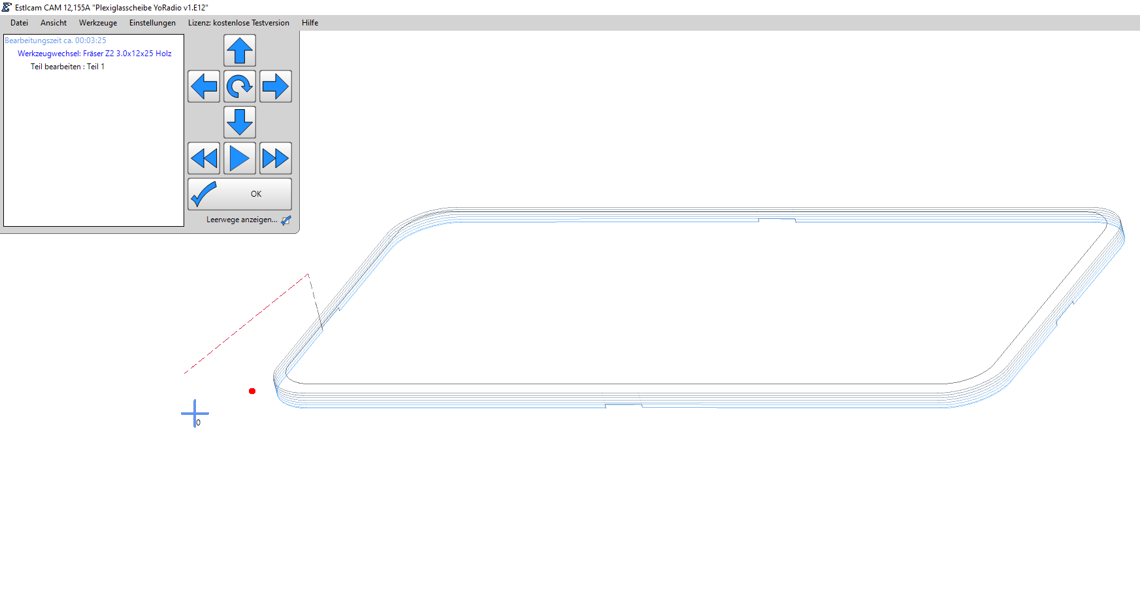
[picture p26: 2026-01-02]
docs/images/cam_05.PNG

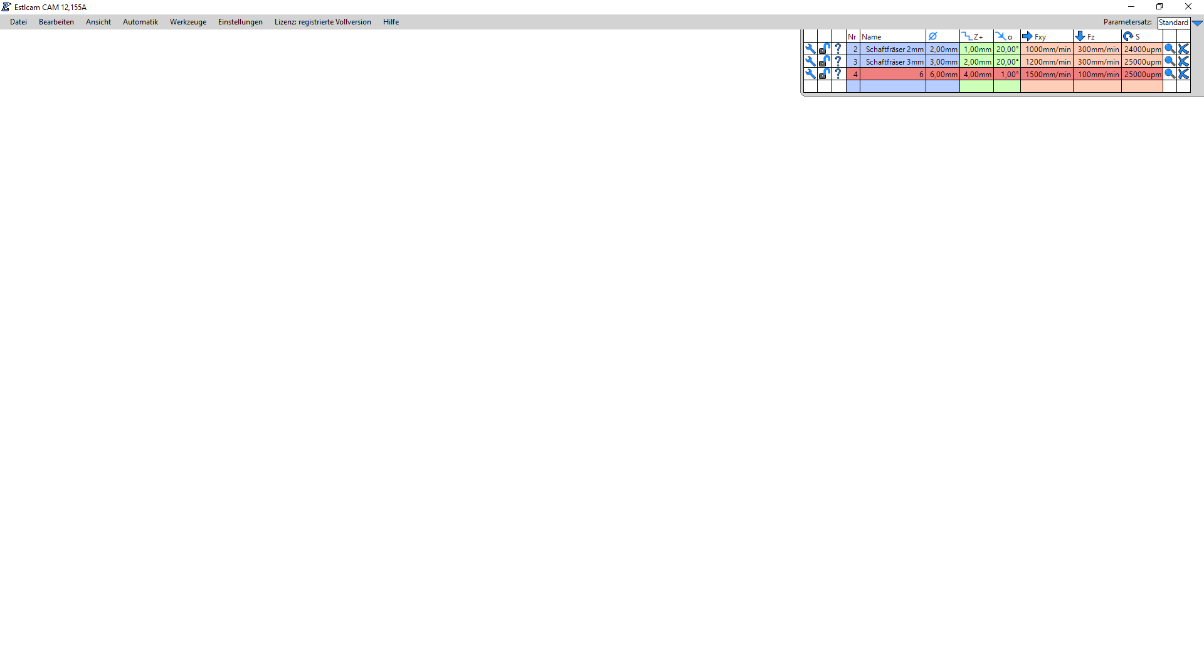
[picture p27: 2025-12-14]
docs/images/screenshot_02.PNG

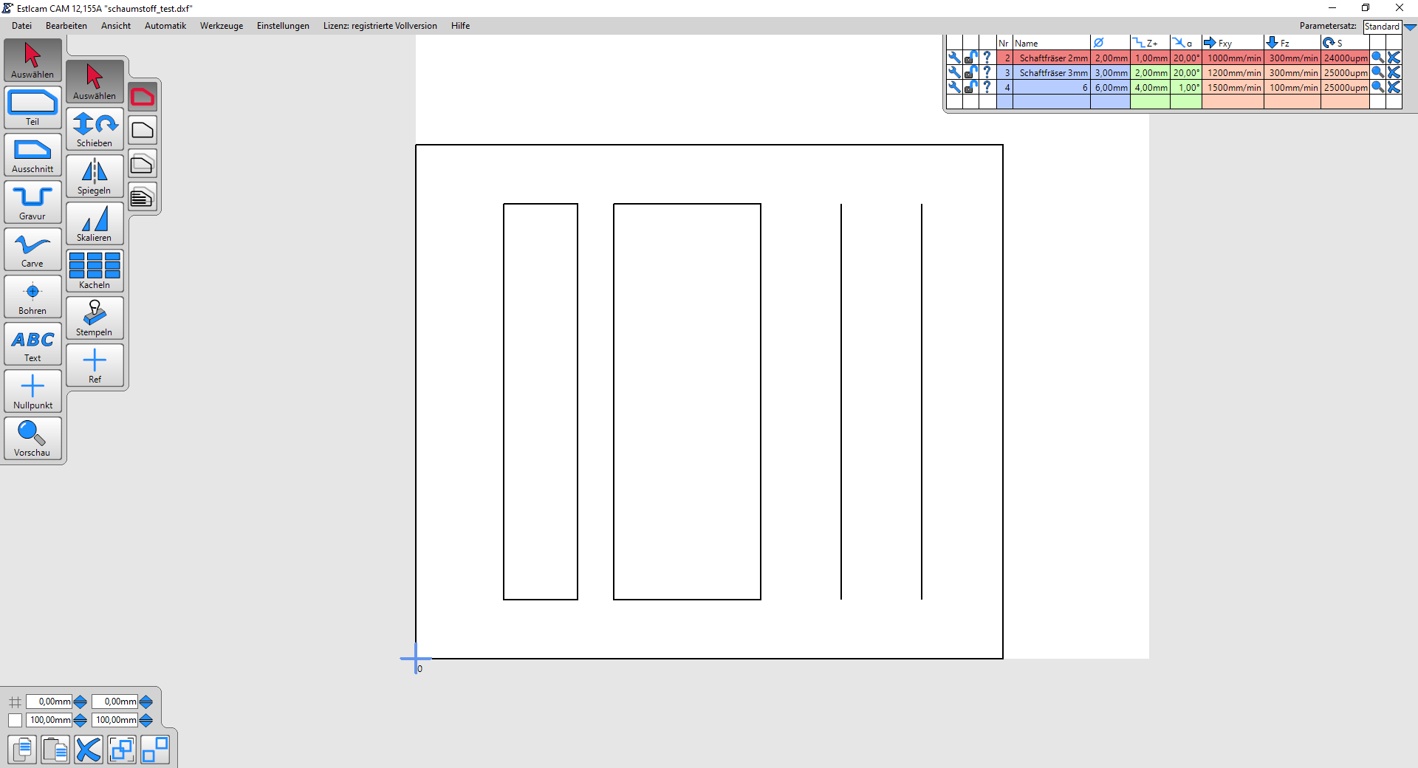
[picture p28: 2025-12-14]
docs/images/screenshot_03.PNG

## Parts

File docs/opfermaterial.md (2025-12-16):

# Opfermaterial

Das Alu-Rohmaterial ist **immer** auf ein Opfermaterial zu spannen, um die Nutenplatte zu schützen. Dafür eignen sich dünne Siebdruck- oder Multiplexplatten, die auf das Maß des Werkstücks gesägt wurden.

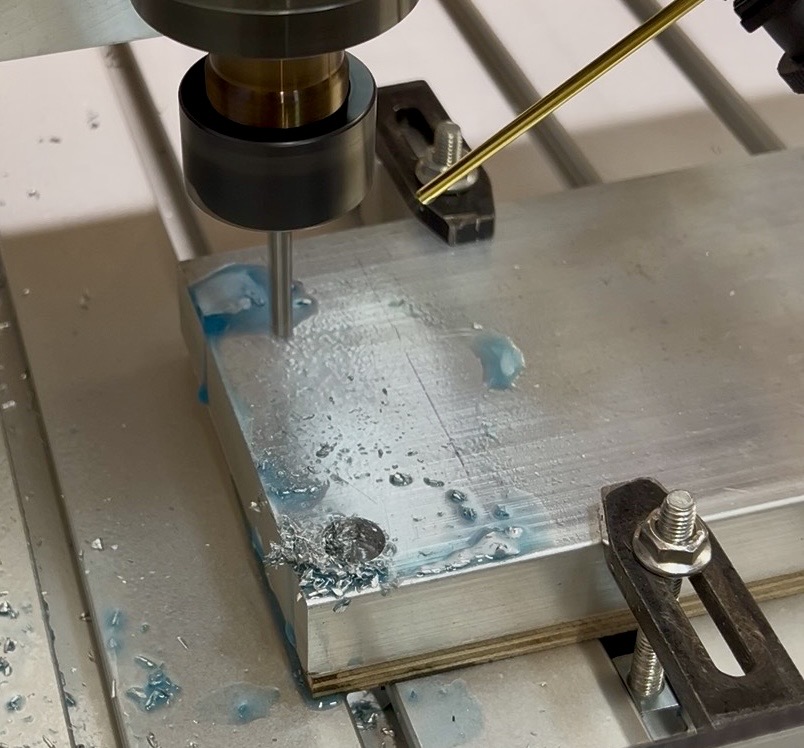
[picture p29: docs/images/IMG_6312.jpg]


[Zurück zum Start](https://makerspace-wi.github.io/Project-CNC-3/#vorbereitung)

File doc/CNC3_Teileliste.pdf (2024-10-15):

Tabelle1

Seite 1

Minimal | Estlcam | Voll
Fräse | Estlcam (China) hat Lieferprobleme
LPT / Parallelport Adapter "Light" | Bestückte Platine | 29,95 €

https://www.estlcam.de/estlcam.php

(Light: MMS Ansteuerung nicht klar)
Klemmen Adapter "XL" | Bestückte Platine | | 89,95 € | 89,95 €
(XL: MMS Ansteuerung vorgesehen)
Handrad | Komplett incl. Kabel | 189,95 € | 189,95 € | 189,95 €

# Minimalmengen Schmierung

ColdEND32 als Komplettbausatz | Bausatz alle Teile | 449,99 € | https://www.end-cnc-shop.de/coldend-sets/33/das-coldend32-als-komplettbausatz
Das kleine ColdEND Set für Bastler | Minimal Teile | 179,99 € | https://www.end-cnc-shop.de/coldend-sets/14/das-kleine-coldend-set-fuer-bastler
Peristaltikpumpe Für das ColdEND | Pumpe | 49,90 €
Das ColdEND Gen. 2 | ColdEnd | | 89,99 €

https://www.end-cnc-shop.de/

ColdEND-Drucktank set 10" inklusive 1/2" Anschlüssen | Tank | 39,90 €
2/2 Ventilset für das ColdEND | Ventil | 34,90 €
Peristaltikpumpe Für das ColdEND | Pumpe | 49,90 €
Schlauch, Anschluß Luft, …. | Rest | ???
Kleinteil | ??? | ??? | ???
Liquid Cool-End (Jokisch Solis Varo S3G) | 1L Gebinde | 5L | 10,90 € | 47,90 € | https://www.end-cnc-shop.de/kuehlschmierstoff/

## Gesamtpreis: 460,69 € 494,59 € 777,79 €

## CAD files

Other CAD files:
docs/Übungsmodell.dxf

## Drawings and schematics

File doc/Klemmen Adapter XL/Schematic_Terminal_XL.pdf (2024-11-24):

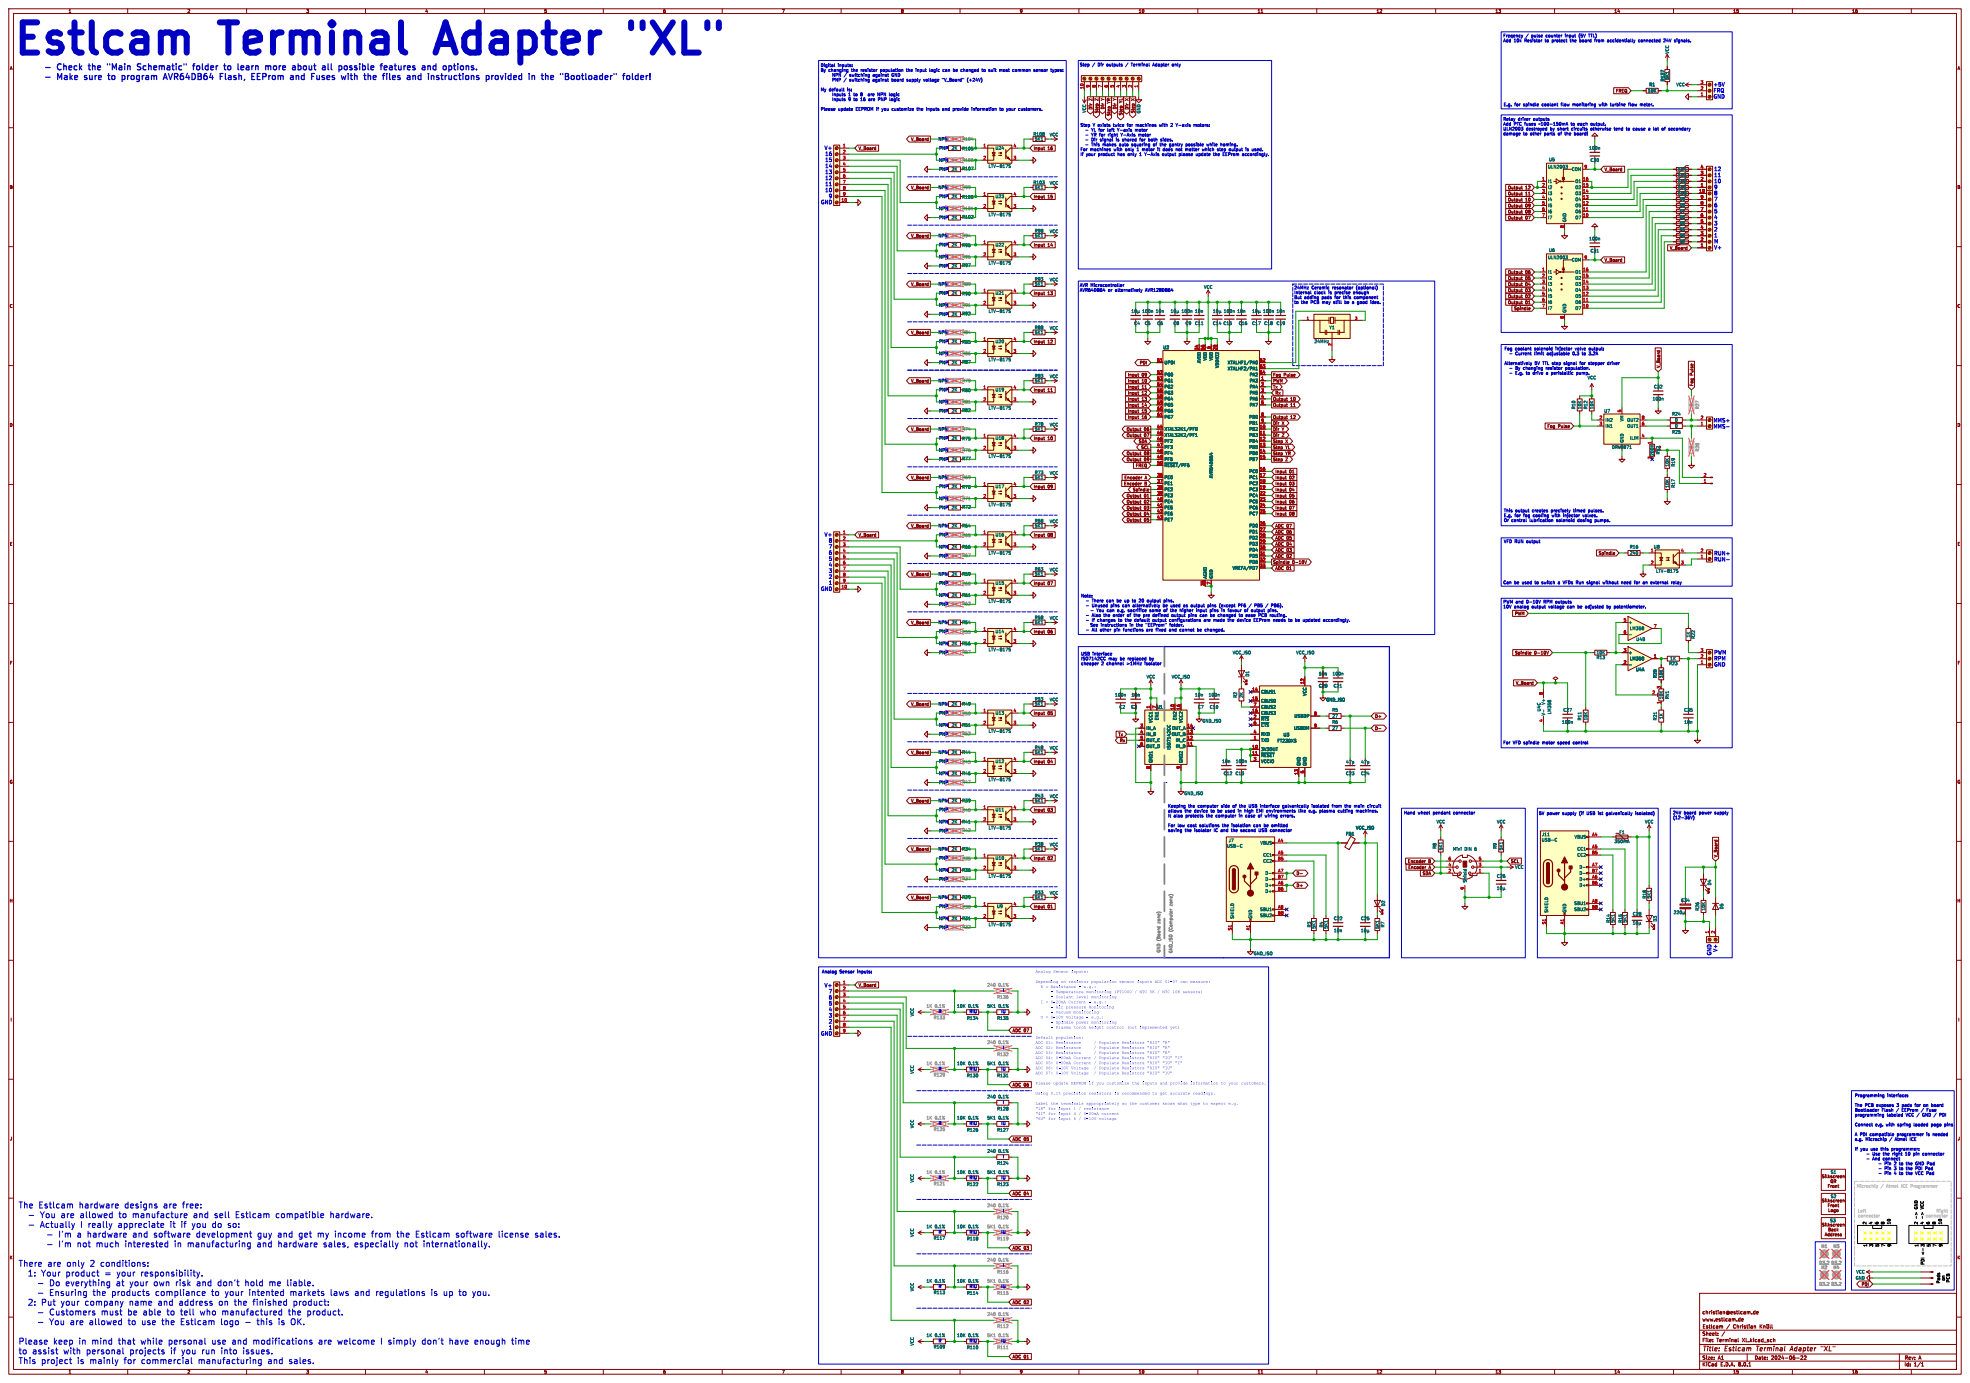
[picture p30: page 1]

Step / Dir outputs / Terminal Adapter only

- YR for right Y-Axis motor

damage to other parts of the board!

If your product has only 1 Y-Axis output please update the EEProm accordingly.

64 GND
Fog Pulse Dir X Output 12

Output 11
Input 03 Step YL Step X

44 XTAL32K2/PF1
SCL Output 08 Output 09 Output 05 Output 04

cheaper 2 channel >1MHz isolator NPN

For VFD spindle motor speed control

7 Programming interface: The PCB exposes 3 pads for on board Bootloader Flash / EEProm / Fuse

- Pin 3 to the PDI Pad
- Pin 4 to the VCC Pad PDI <-

There are only 2 conditions:

to assist with personal projects if you run into issues.

Id: 1/1 Title: Estlcam Terminal Adapter "XL"

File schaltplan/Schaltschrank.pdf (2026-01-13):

0 | 1 | 2 | 3 | 4 | 5 | 6 | 7 | 8 | 9 | 10 | 11

A

B

C

D

E

F

G

Autor: Elian Terelle | CNC3 | Datei:
Datum: | | Seite: 1/8

# CNC3

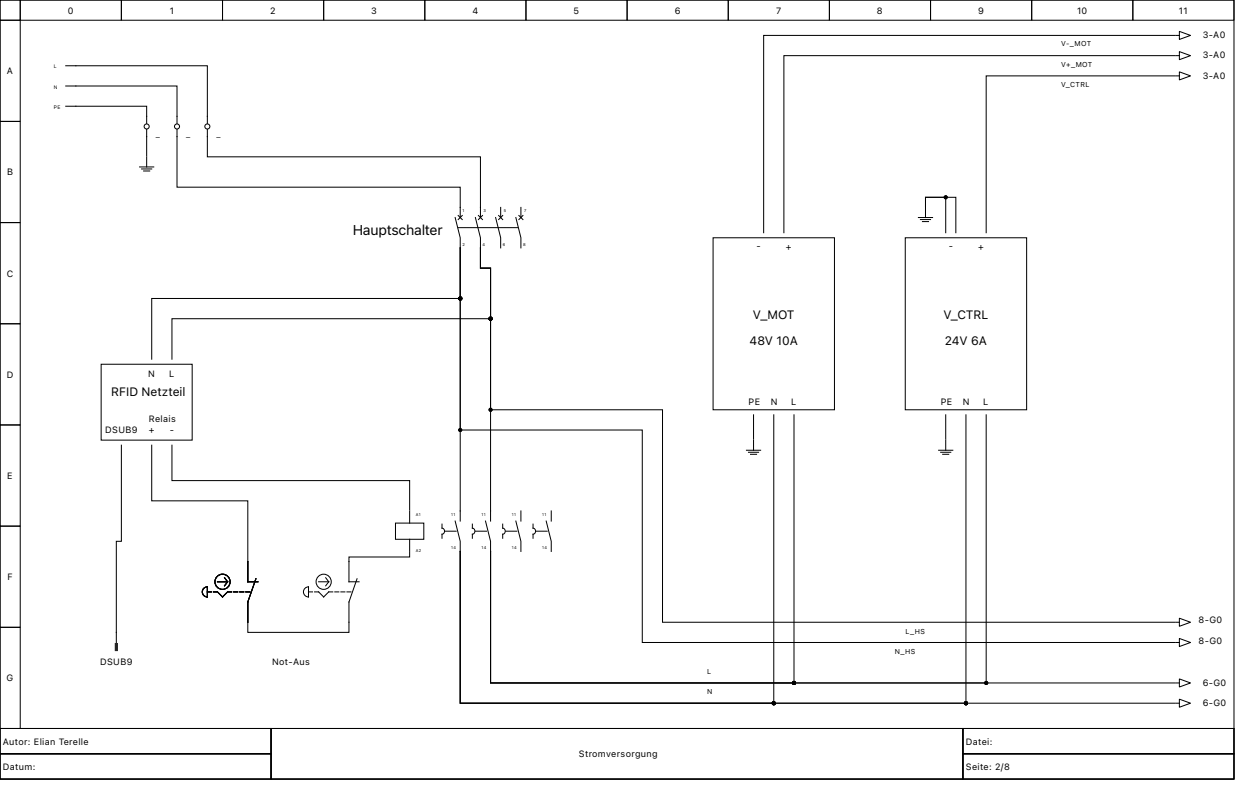
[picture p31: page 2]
Stromversorgung; Datei:; Datum:; Seite: 2/8; Hauptschalter; V_MOT; V_CTRL; RFID Netzteil; DSUB9; Relais +; Not-Aus; V-_MOT; V+_MOT

Autor: Elian Terelle

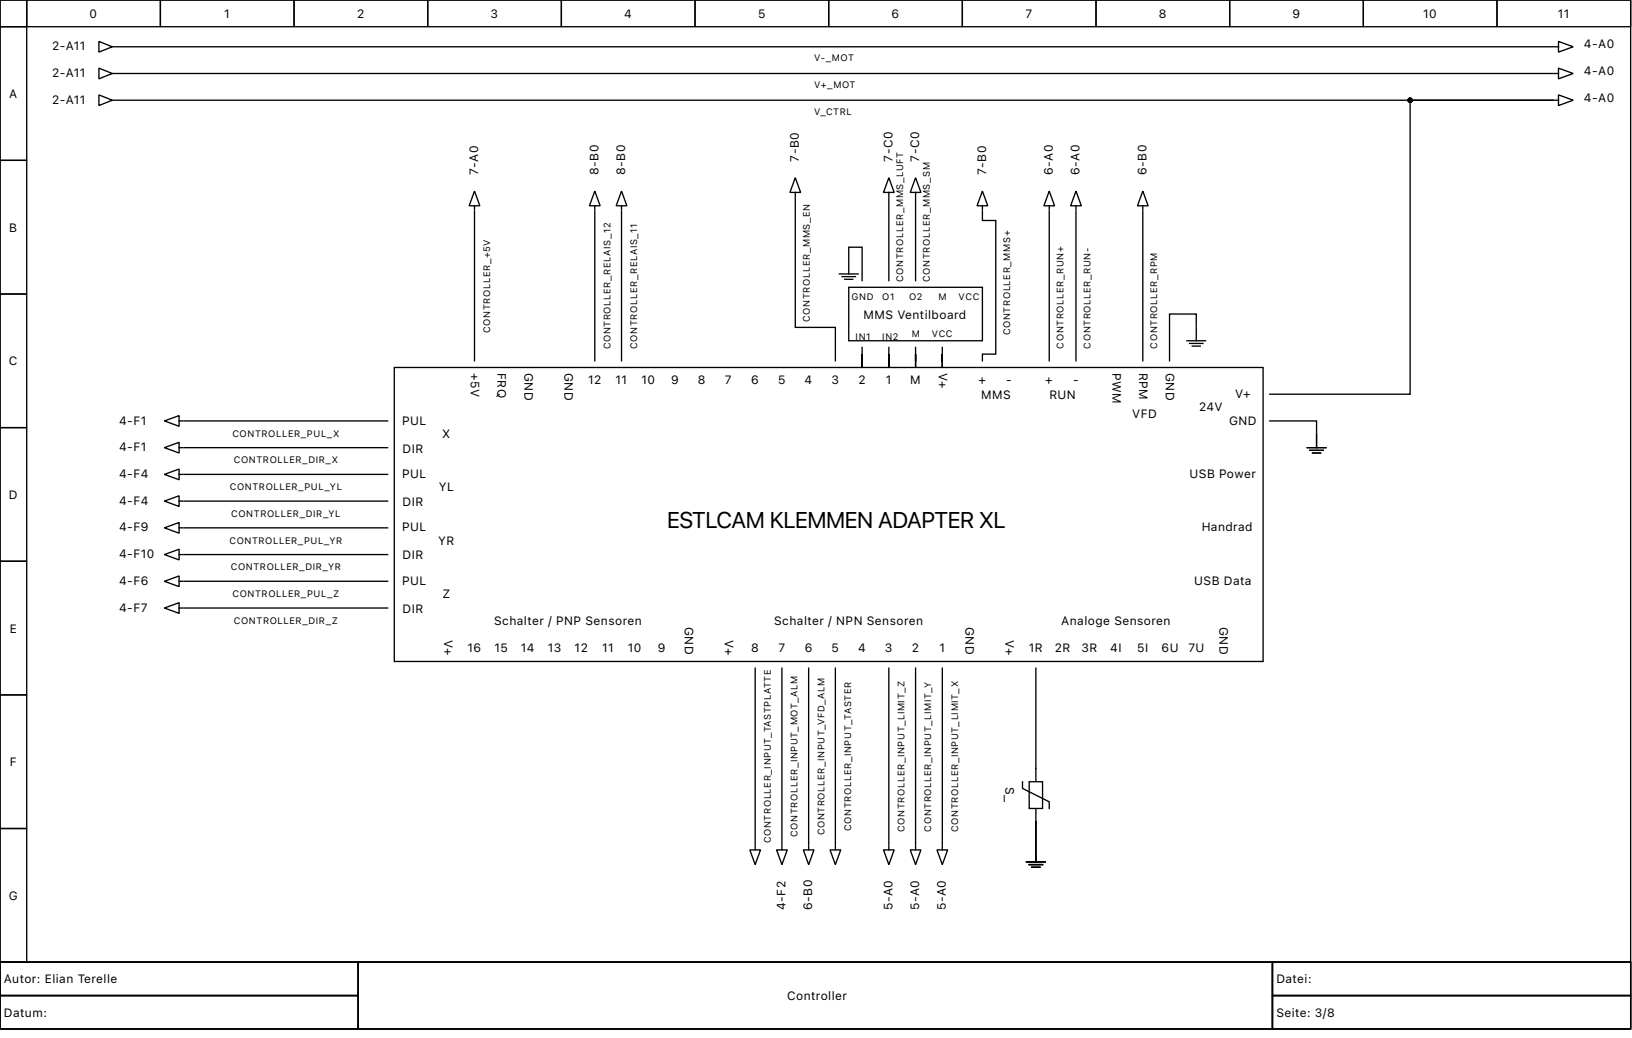
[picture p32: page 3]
ABCDEFGAu; r: Elia; elle; olle; ei: Datum:; Seite: 3; alt; alo; GND; FRQ; PWM; VCC MMS Ventilboard; CONTROLLER_INPUT_VFD_ALM; CONTROLLER_INPUT_TASTPLATTE; CONTROLLER_INPUT_TASTER; CONTROLLER_INPUT_LIMIT_Y; DIR; CONTROLLER_RUN+; CONTROLLER_RPM; CONTROLLER_INPUT_LIMIT_Z; CONTROLLER_INPUT_LIMIT_X; CONTROLLER_+5V; CONTROLLER_RELAIS_11; CONTROLLER_RELAIS_12; CONTROLLER_MMS+; CONTROLLER_INPUT_MOT_ALM; CONTROLLER_RUN- CONTROLLER_MMS_SM; CONTROLLER_MMS_LUFT; CONTROLLER_MMS_EN

DIR PUL PUL DIR PUL
RXYL
DIR

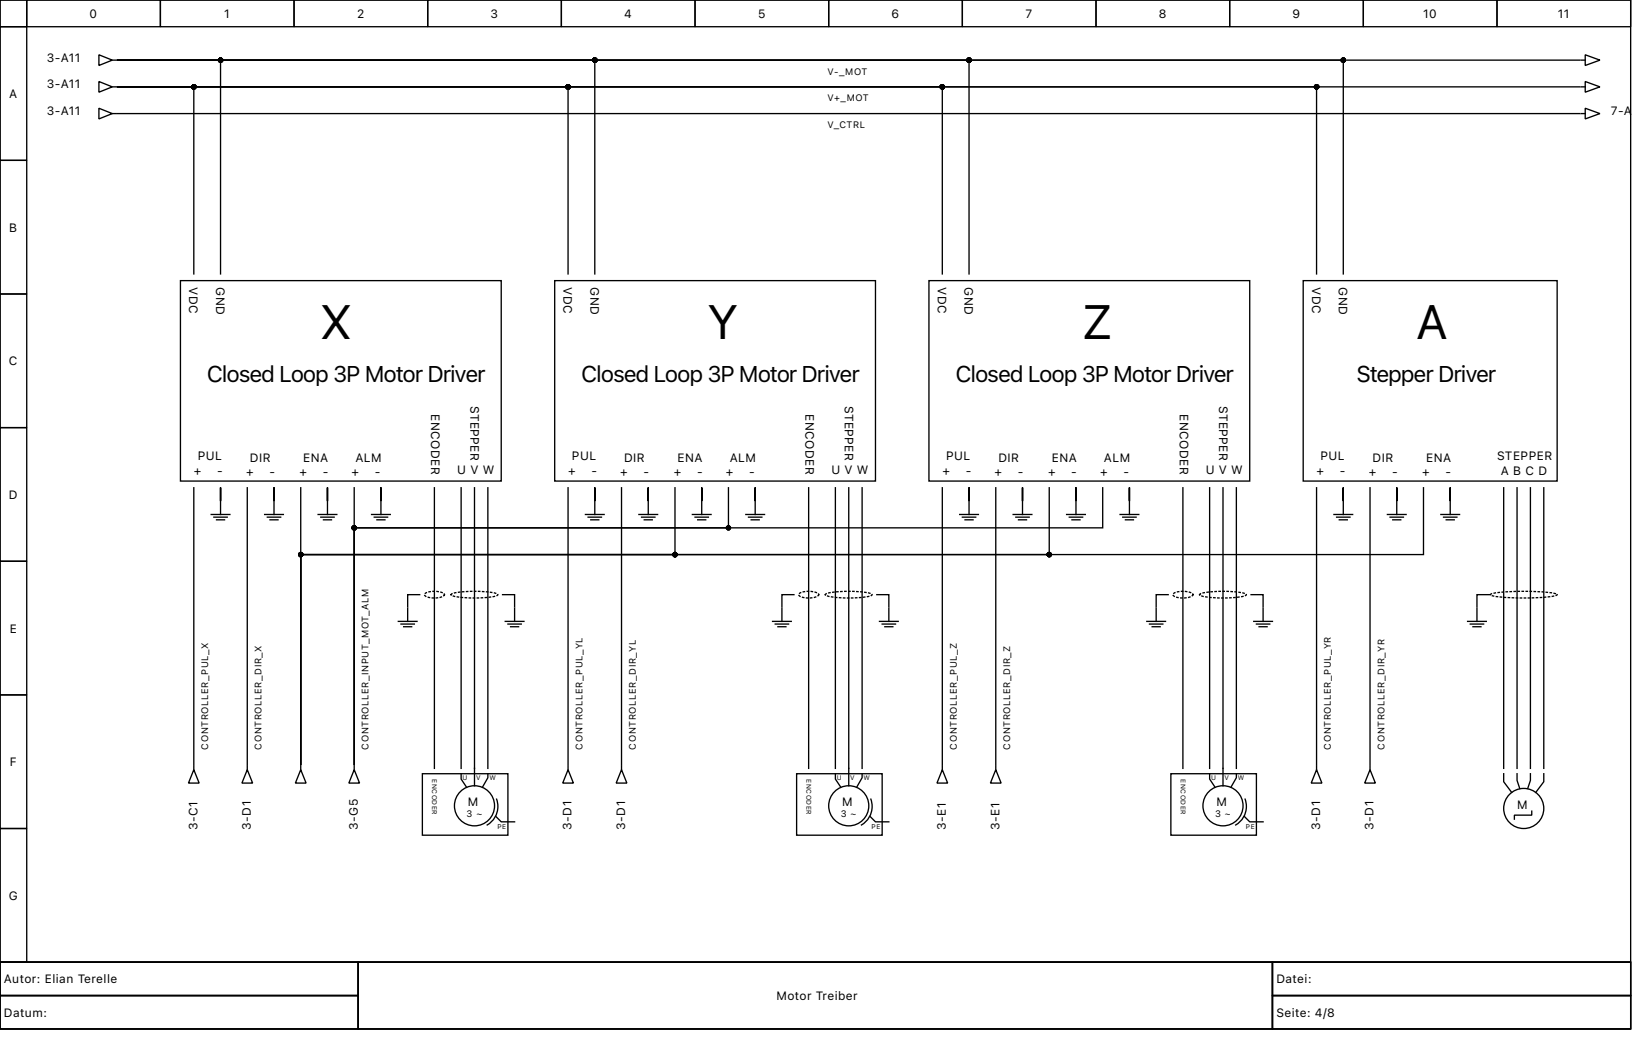
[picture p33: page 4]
Motor Treiber; Datei:; Datum:; Seite: 4/8; ENCODER; PUL + -; STEPPER A B C D; ENA + -; GND; DIR + -; VDC; Stepper Driver; ALM + -; PUL; STEPPER; V_CTRL; V+_MOT; CONTROLLER_DIR_X; CONTROLLER_PUL_YR; V-_MOT; CONTROLLER_INPUT_MOT_ALM; CONTROLLER_PUL_X; CONTROLLER_PUL_Z; CONTROLLER_DIR_YL; CONTROLLER_DIR_Z; CONTROLLER_DIR_YR; CONTROLLER_PUL_YL

Closed Loop3P Motor Driver

Autor: Elian Terelle

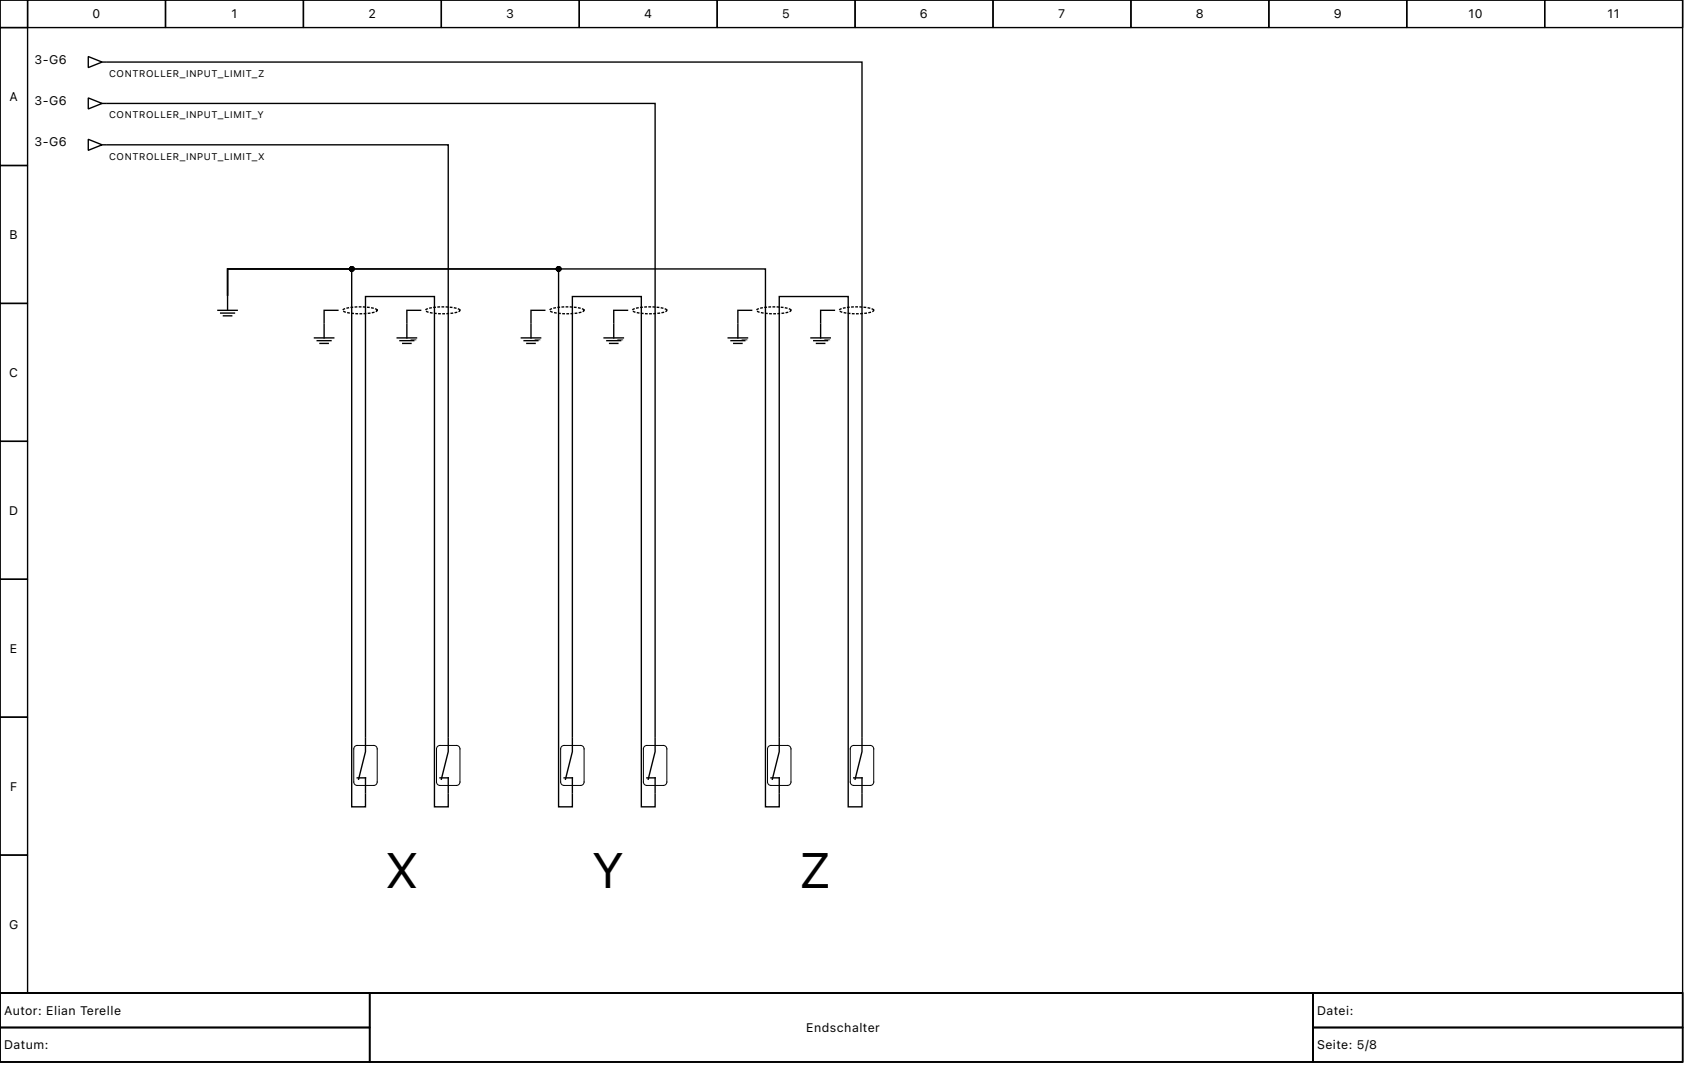
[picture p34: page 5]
Endschalter; Datei:; Datum:; Seite: 5/8; CONTROLLER_INPUT_LIMIT_Z; CONTROLLER_INPUT_LIMIT_Y; CONTROLLER_INPUT_LIMIT_X

Autor: Elian Terelle

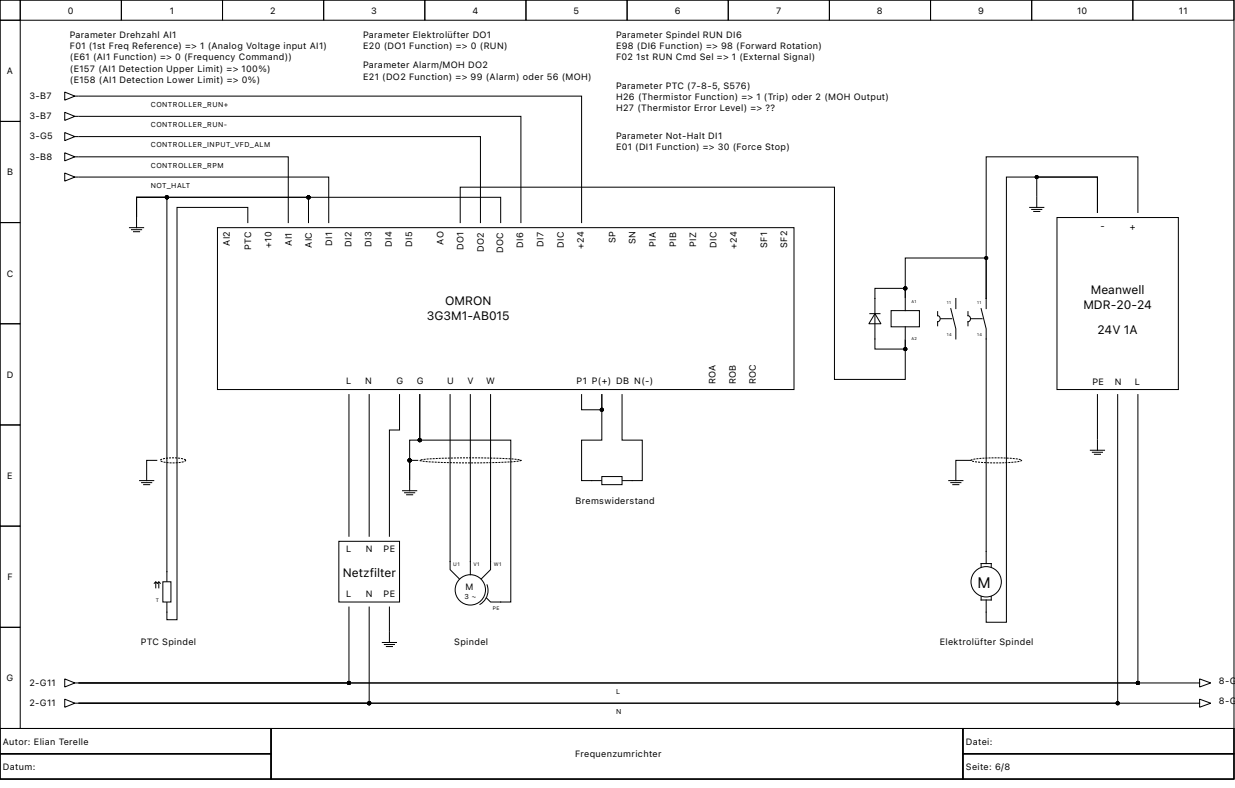
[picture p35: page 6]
Frequenzumrichter; Datei:; Datum:; Seite: 6/8; ROA; ROB; ROC; PIA; AIC; PTC; DIC; DOC; PIZ; PIB; OMRON 3G3M1-AB015; Netzfilter; Meanwell MDR-20-24; Spindel; PTC Spindel; Bremswiderstand; Elektrolüfter Spindel; CONTROLLER_RUN-; CONTROLLER_INPUT_VFD_ALM; CONTROLLER_RPM; CONTROLLER_RUN+; NOT_HALT

Parameter Drehzahl AI1
F01 (1st Freq Reference) => 1 (Analog Voltage input AI1)
(E61 (AI1 Function) => 0 (Frequency Command))
(E157 (AI1 Detection Upper Limit) => 100%)
(E158 (AI1 Detection Lower Limit) => 0%)

Parameter Elektrolüfter DO1
E20 (DO1 Function) => 0 (RUN)
Parameter Alarm/MOH DO2
E21 (DO2 Function) => 99 (Alarm) oder 56 (MOH)

Parameter Spindel RUN DI6
E98 (DI6 Function) => 98 (Forward Rotation)
F02 1st RUN Cmd Sel => 1 (External Signal)

Parameter PTC (7-8-5, S576)
H26 (Thermistor Function) => 1 (Trip) oder 2 (MOH Output)
H27 (Thermistor Error Level) => ??

Parameter Not-Halt DI1
E01 (DI1 Function) => 30 (Force Stop)

Autor: Elian Terelle

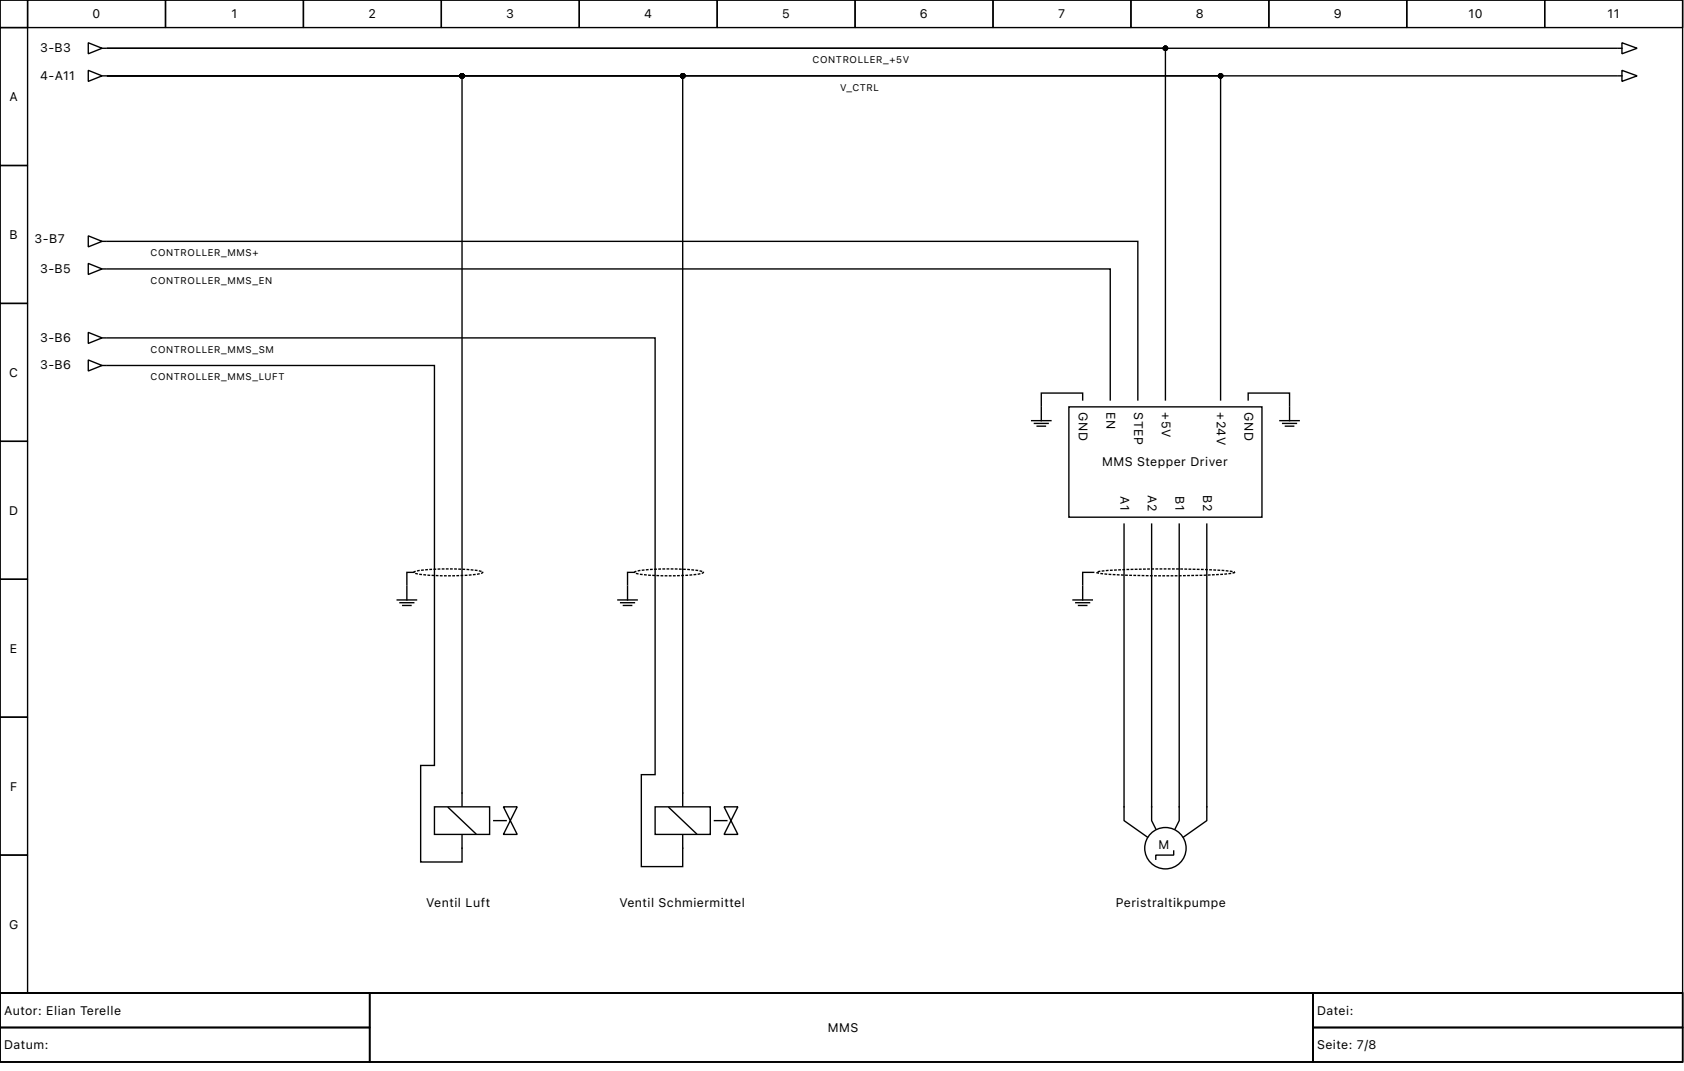
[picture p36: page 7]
MMS; Datei:; Datum:; Seite: 7/8; STEP; GND; Ventil Luft; Ventil Schmiermittel; Peristraltikpumpe; CONTROLLER_MMS_LUFT; CONTROLLER_MMS+; CONTROLLER_MMS_EN; CONTROLLER_MMS_SM; CONTROLLER_+5V; V_CTRL

MMS Stepper Driver

Autor: Elian Terelle

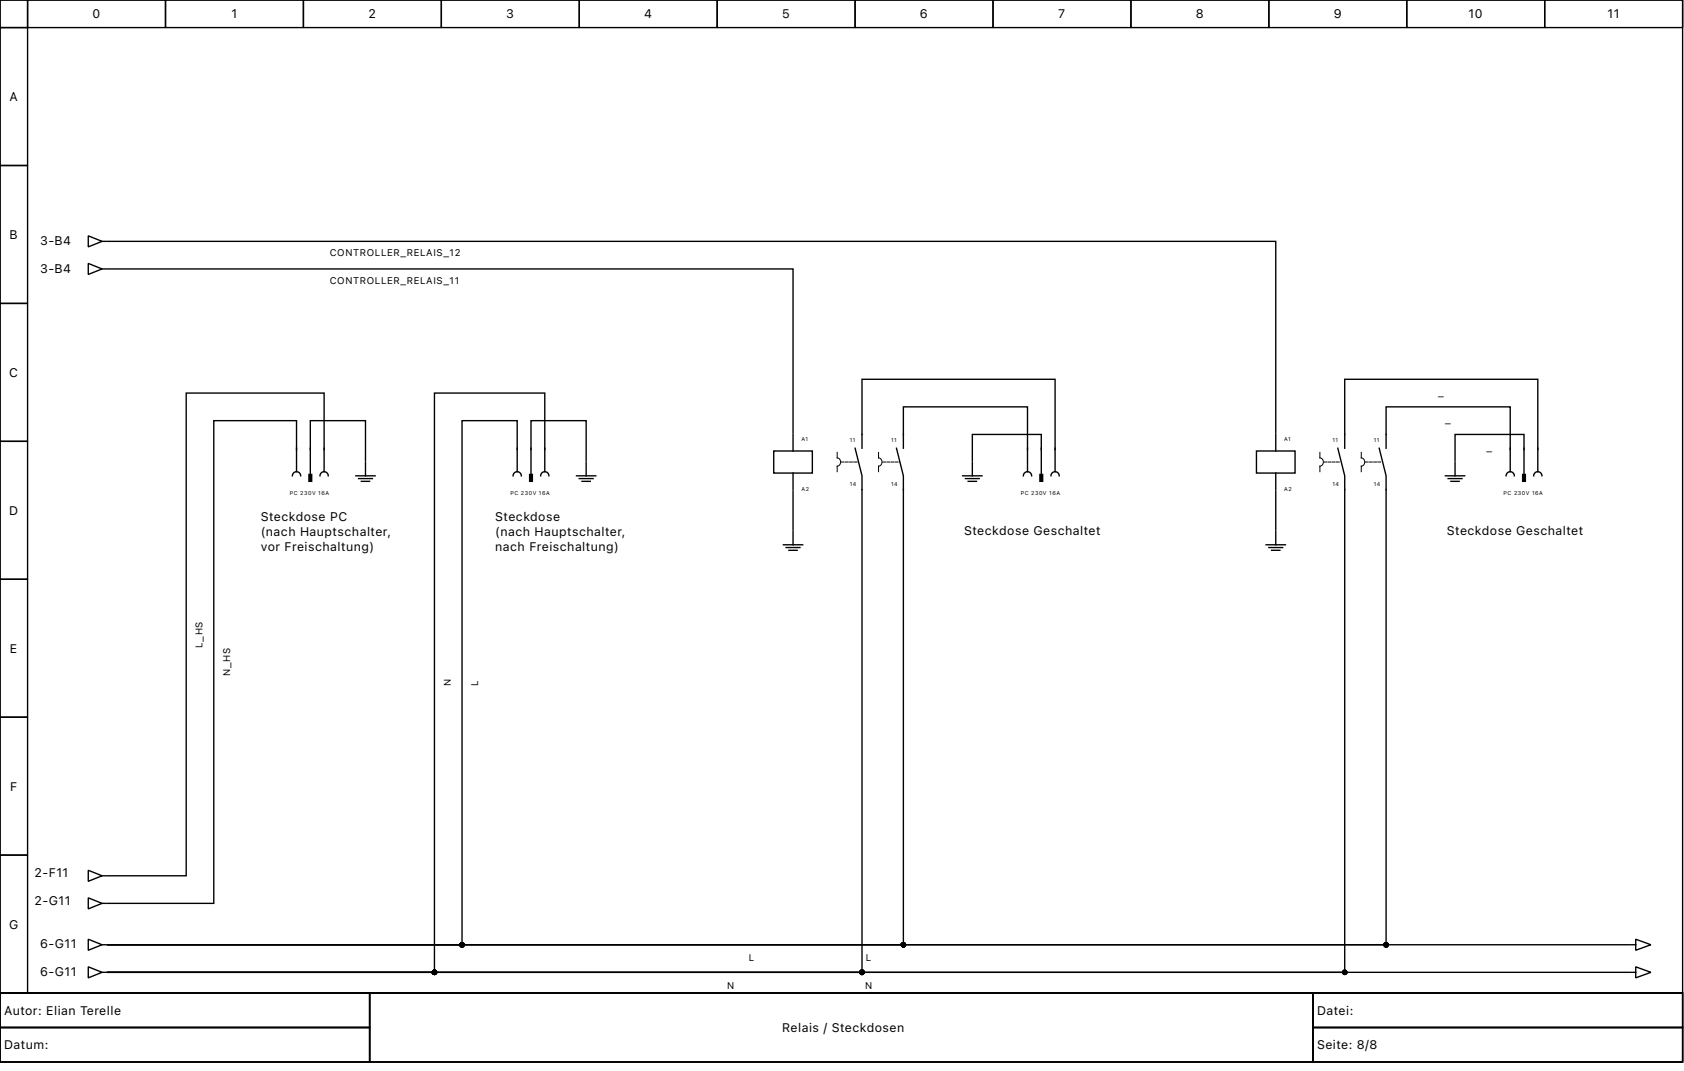
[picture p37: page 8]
Relais / Steckdosen; Datei:; Datum:; Seite: 8/8; Steckdose (nach Hauptschalter, nach Freischaltung); Steckdose Geschaltet; Steckdose PC (nach Hauptschalter, vor Freischaltung); CONTROLLER_RELAIS_12; CONTROLLER_RELAIS_11

Autor: Elian Terelle

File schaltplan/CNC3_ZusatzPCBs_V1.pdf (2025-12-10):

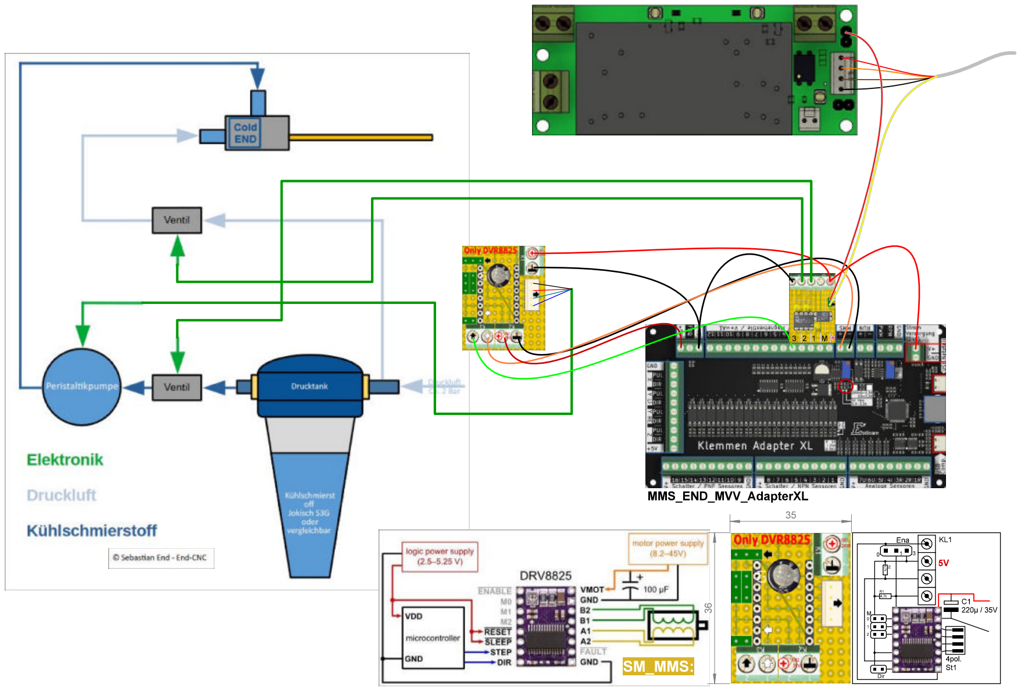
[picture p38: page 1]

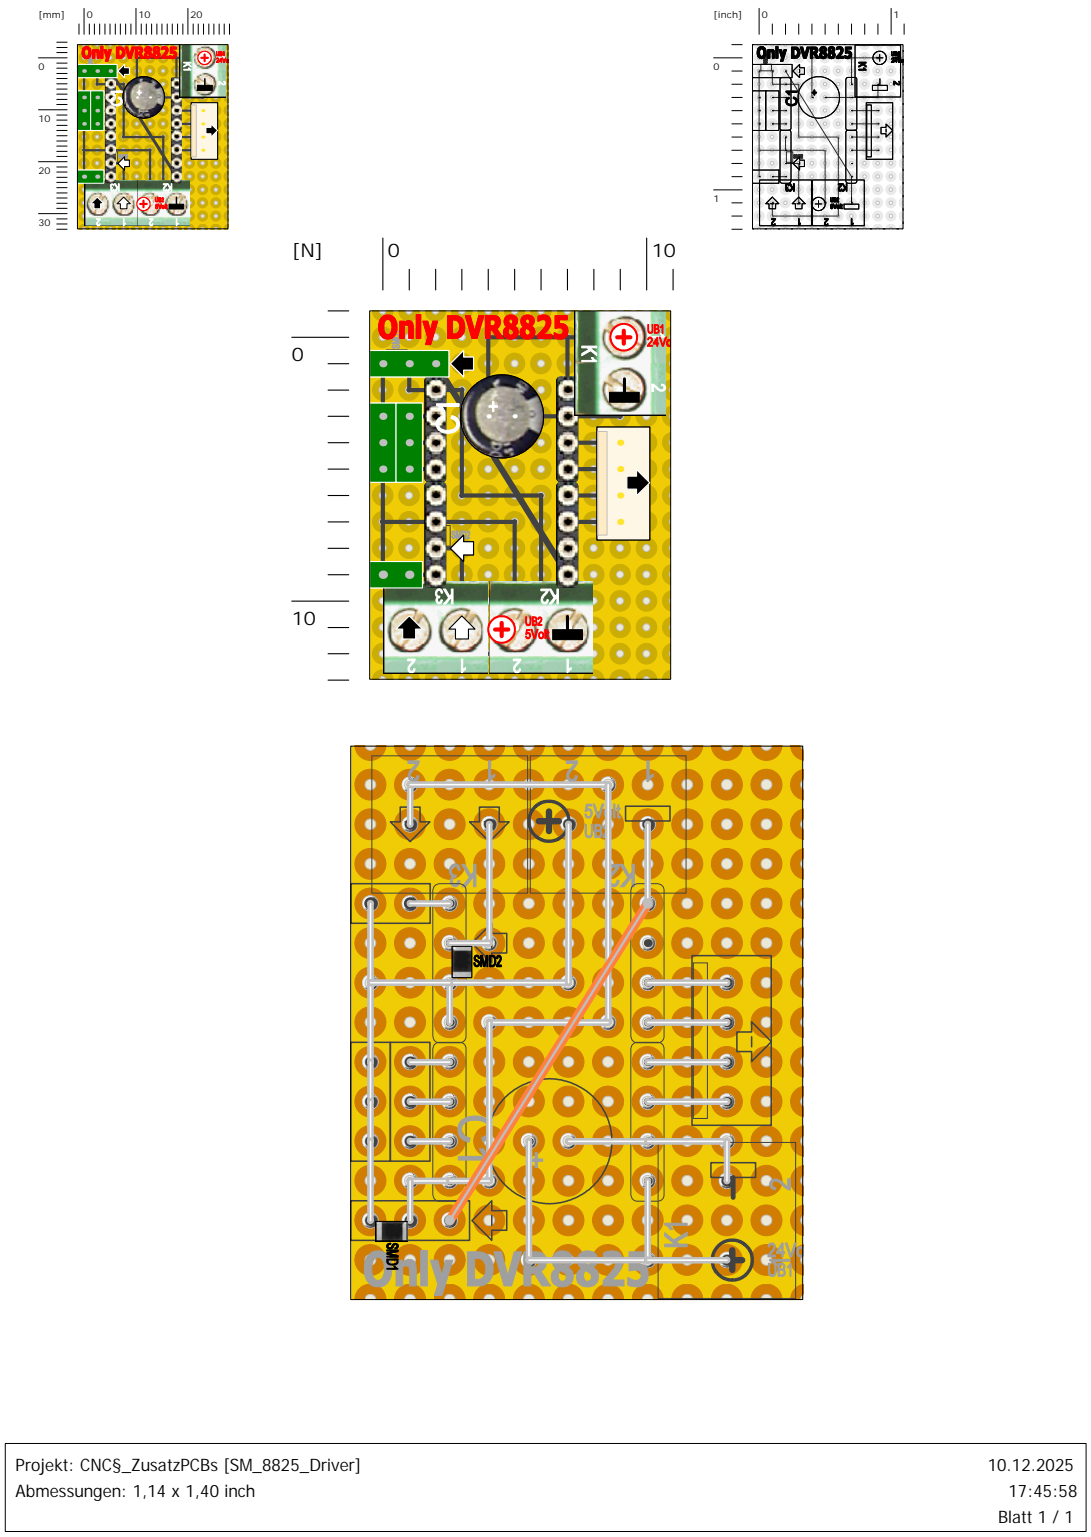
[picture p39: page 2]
[inch]; Projekt: CNC§_ZusatzPCBs [SM_8825_Driver] Abmessungen: 1,14 x 1,40 inch; 10.12.2025 17:45:58 Blatt 1 / 1

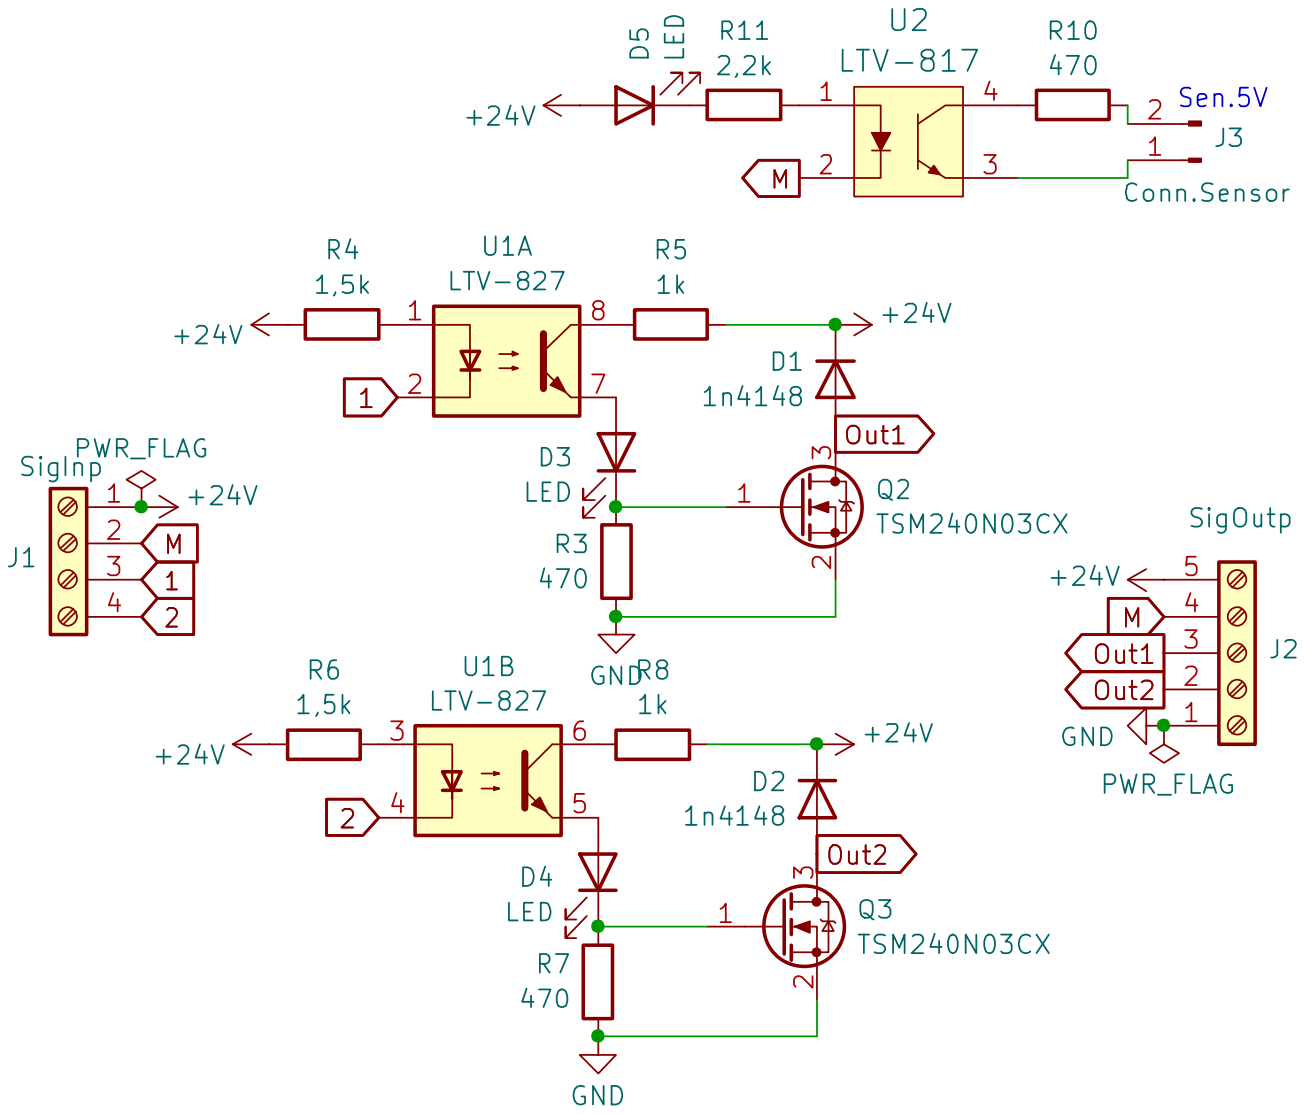
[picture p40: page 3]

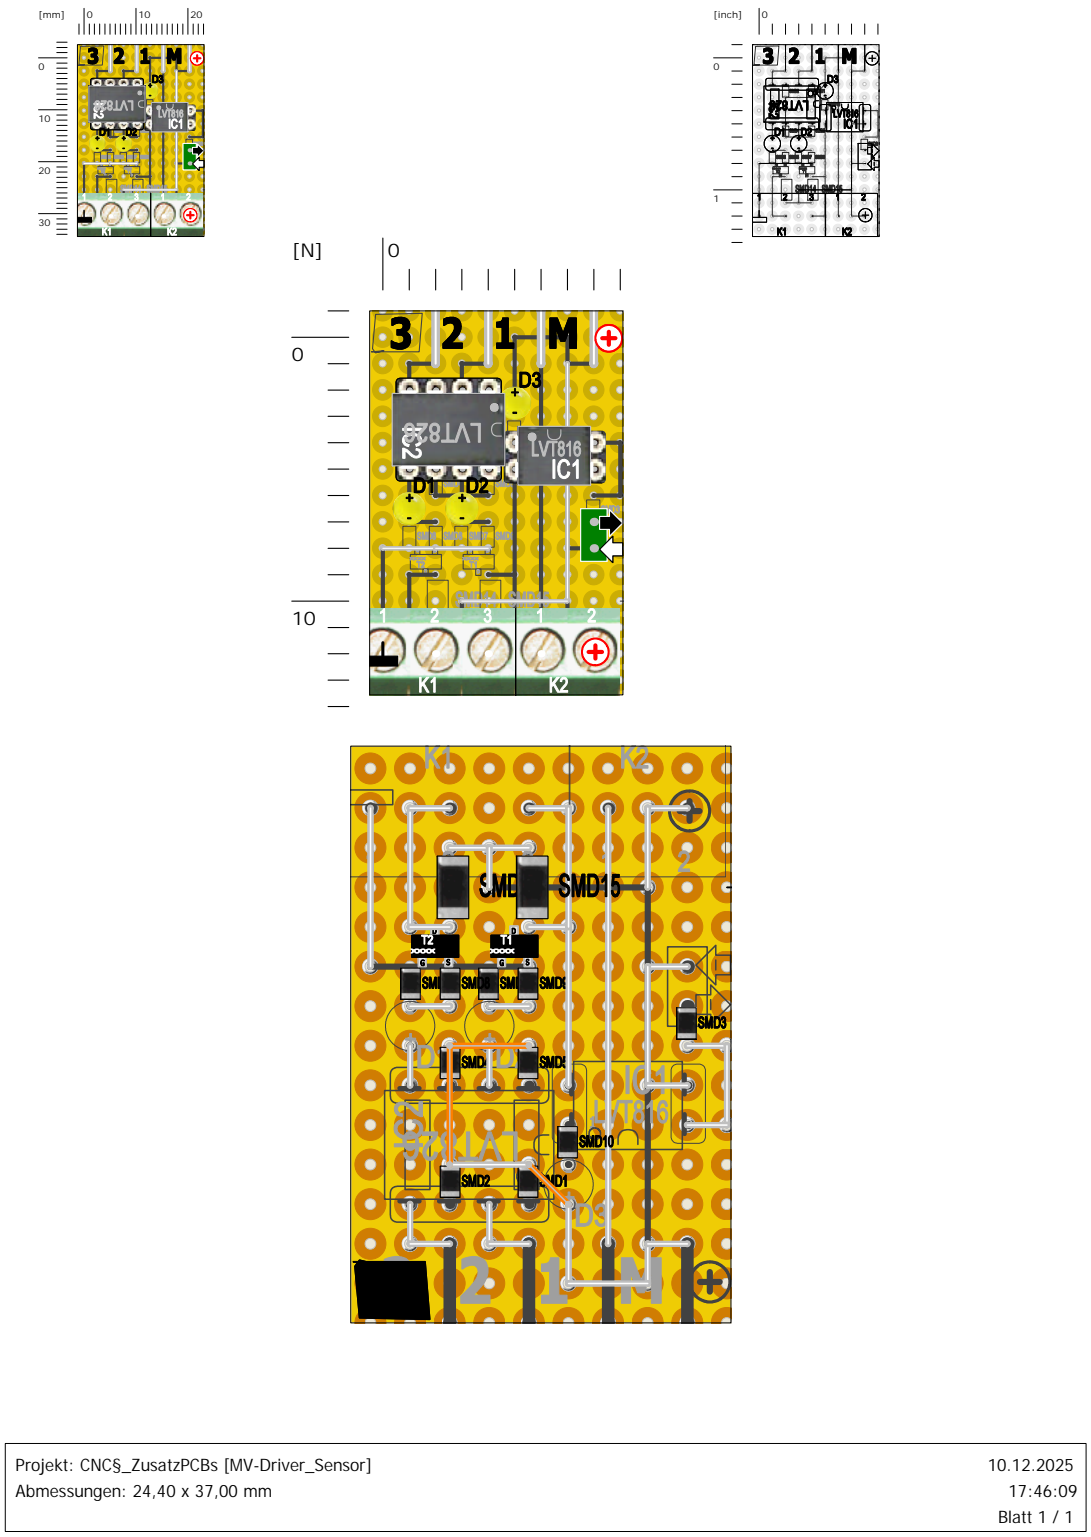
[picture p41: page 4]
[inch]; 10.12.2025 17:46:09 Blatt 1 / 1

Projekt: CNC§_ZusatzPCBs [MV-Driver_Sensor]
Abmessungen: 24,40 x 37,00 mm

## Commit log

2023-04-27 start link assembly docu
2025-02-25 add motor drive and spreadsheed for MMS
2025-08-11 Link zur Anmeldung der CNC-3 aktualisiert
